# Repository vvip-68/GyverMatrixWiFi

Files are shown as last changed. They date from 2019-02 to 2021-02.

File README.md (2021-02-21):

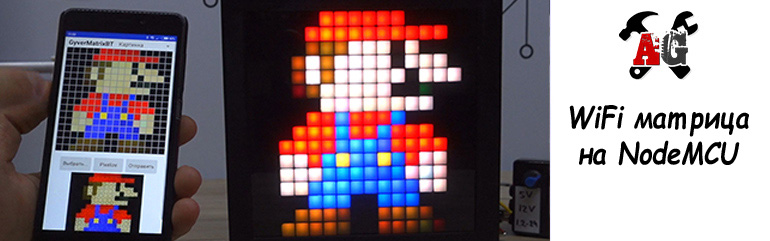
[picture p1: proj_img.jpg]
PROJECT_PHOTO


# Адресная матрица на NodeMCU с управлением по WiFi
* [Описание проекта](#chapter-0)
* [Папки проекта](#chapter-1)
* [Схемы подключения](#chapter-2)
* [Материалы и компоненты](#chapter-3)
* [Как скачать и прошить](#chapter-4)
* [FAQ](#chapter-5)
* [Полезная информация](#chapter-6)

> Этот проект устарел. Новый проект ["Широкоформатная матрица / гирлянда на балкон или стену с управлением по WiFi"](https://github.com/vvip-68/GyverPanelWiFi)
> полностью перекрывает функционал этого проекта, а также имеет множество доработок и улучшений.

## Описание проекта
Этот проект основан на проекте AlexGyver ["Матрица на адресных светодиодах с управлением по Bluetooth"](https://github.com/AlexGyver/GyverMatrixBT)
#### Изменения по справнению с исходным проектом:
 - Поддержка только контроллера с большим объемом памятии наличием WiFi на борту - NodeMCU, Wemos D1 
 - Другие типы контроллеров (типа Arduino Mega + WiFi) - не тестировались.
 - Удалена поддержка управления с кнопок
 - Оставлена одна кнопка управления для переключения режимов, отключения работающего будильника
 - Удалена поддержка управления по Bluetooth
 - Удалена поддержка платы часов реального времени
 - Управление матрицей - через WiFi (локальная сеть)
 - Синхронизация времени с NTP сервером через интернет
 - Адаптированная программа управления матрицей на Andrioid
 - Изменены настройки режимов воспроизведения эффектов
 - Настройки режимов можно изменять из программы со смартфона
   - Яркость матрицы - единая для всех режимов
   - Скорость эффектов - индивидуально для каждого режима
   - Наличие наложения часов на эффекты - индивидуально для каждого режима
   - Включение/исключение режима из списка любимых режимов
 - Настройки сохраняются в энергонезависимой памяти EEPROM
 - К режиму часов добавлен календарь - кратковременное отображение текущей даты поверх эффекта
 - Настройка сервера синхронизации времени
 - Будильник "рассвет", настройки через программу на смартфоне, 7 будильников на каждый день
 - Поддержка звука будильника  / звука рассвета звуковой платой MP3 DFPlayer
 - Настройки сетевого подключения (SSID и пароль, статический IP) задаются в программе и сохраняются в EEPROM
 - Если не удается подключиться к сети (неверный пароль или имя сети) - создается точка подключения
   с именем MatrixAP, пароль 12341234, IP 192.168.4.1. Подключившись к точке доступа из приложения
   можно настроить параметры сети. Если после задания параметиров сети WiFi соединение установлено - 
   в приложении на смартфоне виден IP адрес подключения к сети WiFi.  
 - Быстрое включение режимов лампы белого или заданного цвета из приложения (вся панель светится), 
   выключение панели, комбинация лампы с отображением часов, ночные часы (пониженная яркость).
 - Автоматическая установка яркости матрицы в зависимости от уровня внешней освещенности.
 - Два программируемых по времени режима, позволяющие, например, настроить автоматическое выключение экрана матрицы в ночное время и автоматическое же включение матрицы утром.

## От исходного проекта сохранены следующие возможности:
#### Режимы:
 - Рисование
 - Загрузка картинок
 - Бегущая строка  
#### Эффекты:
 - Снегопад
 - Блуждающий кубик
 - Радуга
 - Огонь
 - The Matrix
 - Летающие частицы
 - Звездопад
 - Пейнтбол
 - Водоворот
 - Шумовые эффекты с разными цветовыми палитрами
 - Анимация
 - Часы  
#### Игры:
 - Змейка
 - Tетриc
 - Лабиринт  
 - Арканоид
 - Runner
#### Возможности:
- Автоподключение к матрице при запуске
- Настройки яркости и скорости отображения
- Использование акселерометра в играх

### Кнопка управления режимами, последовательность переключения:
#### Будильник сработал, идет рассвет или мелодия пробуждения
- Любое нажатие кнопки отключает будильник
#### Долгое удержание кнопки (более 3 секунд)
- Если матрица включена, она будет выключена (черный экран)
- Если матрица выключена (черный экран) - включается режим часов
#### Однократное нажатие кнопки
- Если матрица включена в режиме часов, происходит переключение часов по циклу:
  - Часы на черном фоне
  - Часы на фоне огня (камин)
  - Ночные часы
- Если матрица включена в режим лампы (белый экран) - вкл / выкл отображения часов.
- Если работают демо-режимы -  переход к следующему режиму
#### Двухкратное нажатие кнопки
- Из любого режима включается режим часов на черном фоне
- Из режима часов переключается в режим лампы
#### Трехкратное нажатие кнопки
- Включается демо-режим
#### Четырехкратное нажатие кнопки
- На экране матрицы в режиме бегущей строки отображается IP адрес матрицы, если подключение к локальной WiFi сети установлено

## Папки
**ВНИМАНИЕ! Если это твой первый опыт работы с Arduino, читай [инструкцию](#chapter-4)**
- **libraries** - библиотеки проекта.
- **firmware** - прошивки для NodeMCU
- **schemes** - схемы подключения компонентов
- **sounds** - звуковые файлы будильника для размещения на SD-карте
- **Android** - файлы с приложениями, примерами для Android и Thunkable
- **image decoding** - папка с инструментами для загрузки картинок и гифок

## Схемы
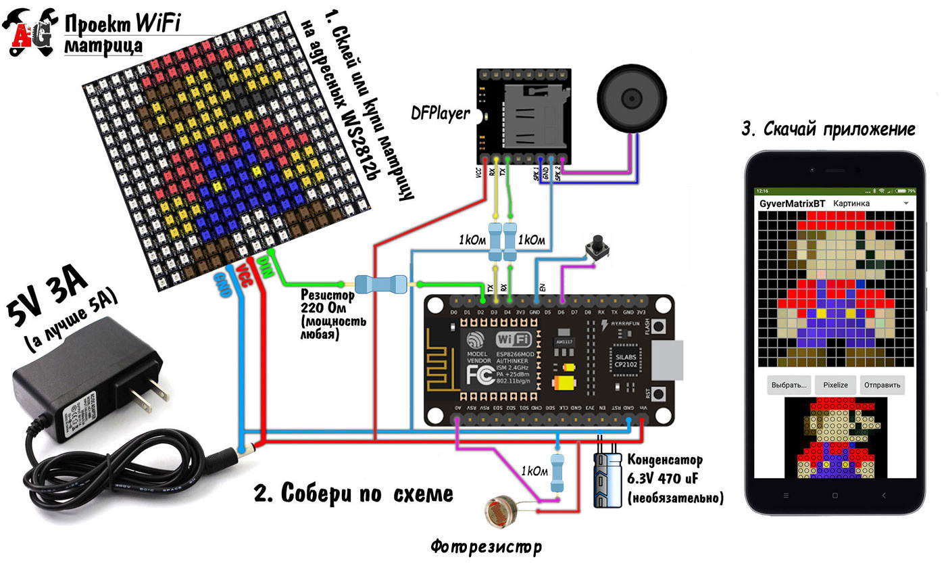
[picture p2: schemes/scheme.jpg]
SCHEME


## Материалы и компоненты
### Ссылки оставлены на магазины
Полный список компонентов есть в статье https://alexgyver.ru/matrix_guide/
- NodeMCU http://ali.onl/1dVU http://ali.onl/1dVV
- Матрицы разные http://ali.ski/pw2ic
- Лента http://ali.ski/YdfMN
- Модульная гирлянда http://ali.ski/0h35RR
- Резисторы http://ali.ski/UEez2
- БП 5 Вольт http://ali.ski/3cNyj  http://ali.ski/qSKFK
- MP3 DFPlayer http://ali.onl/1gY1 http://ali.onl/1gY3
- Динамики http://ali.onl/1h3u http://ali.onl/1h3v

## Вам скорее всего пригодится
* [Всё для пайки (паяльники и примочки)](http://alexgyver.ru/all-for-soldering/)
* [Недорогие инструменты](http://alexgyver.ru/my_instruments/)
* [Все существующие модули и сенсоры Arduino](http://alexgyver.ru/arduino_shop/)
* [Электронные компоненты](http://alexgyver.ru/electronics/)
* [Аккумуляторы и зарядные модули](http://alexgyver.ru/18650/)

## Как скачать и прошить
* [Первые шаги с Arduino](http://alexgyver.ru/arduino-first/) - ультра подробная статья по началу работы с Ардуино, ознакомиться первым делом!
* Скачать архив с проектом
> На главной странице проекта (где ты читаешь этот текст) вверху справа зелёная кнопка **Clone or download**, вот её жми, там будет **Download ZIP**
* Установить библиотеки в  
`C:\Program Files (x86)\Arduino\libraries\` (Windows x64)  
`C:\Program Files\Arduino\libraries\` (Windows x86)
* **Подключить внешнее питание 5 Вольт**
* Подключить Ардуино к компьютеру
* Запустить файл прошивки (который имеет расширение .ino)
* Настроить IDE (COM порт, модель Arduino, как в статье выше)
* Настроить что нужно по проекту
* Нажать загрузить
* Скачать и установить на смартфон GyverMatrix
* Пользоваться  

**Подробная инструкция [тут](https://github.com/vvip-68/GyverMatrixWiFi/wiki/%D0%9F%D0%BE%D0%B4%D0%B3%D0%BE%D1%82%D0%BE%D0%B2%D0%BA%D0%B0-%D1%81%D1%80%D0%B5%D0%B4%D1%8B-%D0%B4%D0%BB%D1%8F-%D1%81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)**

## Важно
Если проект не собирается (ошибки компиляции) или собирается, но работает неправильно (например вся матрица светится белым и ничего не происходит) - проверьте версии библиотек. Данный проект рассчитан на работу с версииями библиотек поддержки плат ESP версии 2.5.2 и библиотеки FastLED версии 3.2.9 или более новую;

Если в качестве микроконтроллера вы используете Wemos D1 - в менеджере плат для компиляции все равно выбирайте **"NodeMCU v1.0 (ESP-12E)"**, в противном случае, если выберете плату Wemos D1 (xxxx), - будет работать нестабильно, настройки не будут сохраняться в EEPROM, параметры подключения к локальной сети будут сбрасываться каждый раз при перезагрузке, плата вместо подключения к локальной сети будет каждый раз создавать точку доступа.

## FAQ
### Основные вопросы
В: Как скачать с этого грёбаного сайта?  
О: На главной странице проекта (где ты читаешь этот текст) вверху справа зелёная кнопка **Clone or download**, вот её жми, там будет **Download ZIP**

В: Скачался какой то файл .zip, куда его теперь?  
О: Это архив. Можно открыть стандартными средствами Windows, но думаю у всех на компьютере установлен WinRAR, архив нужно правой кнопкой и извлечь.

В: Я совсем новичок! Что мне делать с Ардуиной, где взять все программы?  
О: Читай и смотри видос http://alexgyver.ru/arduino-first/

В: Вылетает ошибка загрузки / компиляции!   
О: Читай тут: https://alexgyver.ru/arduino-first/#step-5

### Вопросы по этому проекту

В: Эй чувак! У тебя проект не компилится. Ты файл DFRobotDFPlayerMini.h в проект забыл включить. Выложи!   
О: Это стандартная библиотека для MP3 DFPlayer. Идите в менеджер библиотек и установите ее. Или скачайте с [сайта производителя](https://github.com/DFRobot/DFRobotDFPlayerMini)

В: Эй чувак! У тебя проект не компилится. Ты файл FastLed.h в проект забыл включить. Выложи!   
О: Это стандартная библиотека для FastLed для управления адресными светодиодами. Идите в менеджер библиотек и установите ее. Или скачайте с [сайта производителя](https://github.com/FastLED/FastLED)

В: Собрал, использую NodeMCU/Wemos. Ничего не работает! Мигает один или несколько светодиодов в начале матрицы. И всё.   
О: Производители разных плат (NodeMCU, Wemos) могут использовать различные схемы соединения контактов микроконтроллера ESP8266 к выводам макетной платы. Обычно используемый в проекте пин вывода на ленту приходится или на пин D2 или на пин D4. Для проверки не подключайте сигнальный провод матрицы к микроконтроллеру, вместо этого через резистор коснитесь вывода D2 или D4 пина микроконтроллера. Большая вероятность что матрица заработает с тем или иным вариантом подключения.

В: Собрал, использую NodeMCU. Эффекты работают, но нестабильно. Случайные вспышки на матрице. Буквы бегущей строки прыгают.   
О: NodeMCU v3 чрезвычайно требователен к источнику питания. Ему на вход VIN нужно подавать напряжение в диапазоне 4.7-5 вольт. И не более. Описанные эффекты возникают даже при питании в 5.25 (а тем более - 5.45) вольт. Для проверки - не подключайте +5 вольт от блока питания к NodeMCU совсем, питание подавайте на матрицу непосредственно. Землю NodeMCU и ленты соедините. Подключите сигнальный пин NodeMCU ко входу DIN ленты. Подключите NodeMCU к компьютеру через USB (питание будет поступать отсюда). Должно заработать. Далее регулируйте выходное напряжение своего блока питания.  
В особо тяжелых случаях, когда понижение напряжения питания системы не приводит к желаемым результатам и артефакты, вспышки, дрожание текста бегущей строки продолжается, можно использовать дополнительно схему преобразования уровня от 3.3 вольта с выхода NodeMCU к 5 вольтам входа адресной ленты:  
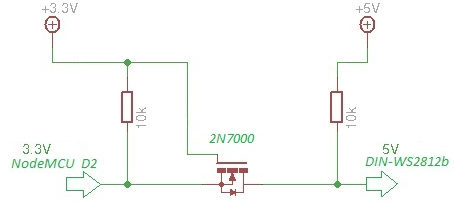
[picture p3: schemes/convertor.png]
SCHEME


В: Не компилируется. Выбрана плата "голая ESP8266-12E". Сообщение об ошибке: "D4 was not declared in this scope."   
О: Очевидно производители библиотеки для "голой ESP8266-12E" не определили данную константу. Используйте всесто константы D4 числовое определение пина для вашей платы или выполните компиляцию проекта для плат NodeMCU или WeMos D1 R2.

В: Не компилируется. В сообщении об ошибке содержатся сведения о дублирующихся библиотеках.    
О: В вашей среде установлено две версии одной и той же библиотеки. Обычно это библиотека FastLED - одна версия находится в папке установки среды Ардуино (например в "C:\Program Files (x86)\Arduino\libraries\"), другая - в папке документов пользователя (например "C:\Users\vvip-68\Documents\Arduino\libraries\"). Удалите одну из версий библиотек и попробуйте скомпилировать снова.

В: Не компилируется. В сообщении об ошибке что-то про несоответствие типов.   
О: Обычно такая ситуация возникает в двух случаях:
- выбрана неверная плата. Используйте NodeMCU 1.0 (ESP-12E Module) или Wemos D1 R1. Под эти платы проект собирается, под другие, возможно, нужна модификация кода.
- установлена устаревшая версия библиотек поддержки плат - например для ESP8266 версия библиотеки 2.4.2. Данный проект использует библиотеки для плат ESP8266 версии 2.5. Обновите библиотеки поддержки плат.

В: Подскажите, что не так... C подключением через точку доступа всё исправно работает, а при попытке подключиться к локальной сети не могу законнектиться через приложение. В чем может быть проблема?  
О: Проблема может быть в неправильно указанном статическом адресе / параметрах сети в прошивке. В сектче по умолчанию используется адрес в сети 192.168.**0**.xxx. Ваш WiFi роутер в зависимости от настроек может создавать сеть в другом диапазоне. Чаще всего это 192.168.**1**.xxx или 192.168.**100**.xxx; Проверьте какую сеть создает ваш роутер и укажите в скетче и при подключении приложения к сети именно эту сеть.

В: Автор неверно указал IP адрес матрицы 192.168.4.1 в режиме точки доступа. На самом деле он 192.168.4.2 - указываю его, приложение на смартфоне подключается. Правда управлять матрицей не получается все равно - она не реагирует на изменения.     
О: Нет, все правильно. IP матрицы - 192.168.4.1; Адрес 192.168.4.2 получает ваш смартфон при подключении к точке доступа. Когда в приложении для подключения вы указываете адрес 192.168.4.2 - вы подключаете ваш смартфон с самому себе, а не к матрице. Естественно никакое управление матрицей работать не будет.   

В: Матрица создает точку доступа, телефон к ней подключается. В приложении ввожу IP адрес матрицы 192.168.4.1, но соединение не происходит. Что я делаю не так?     
О: Некоторые телефоны не могут передавать данные через точку доступа, пока в них активен мобильный интернет. Все передаваемые данные отправляются в интернет, вместо передачи их в точку доступа. В настройках телефона выключите мобильный интернет ("Мобильные данные"). После этого телефон из приложения должен подключиться к матрице.  

В: В скетче есть настройки который задают имя и пароль к локальной сети. Указываю, но к сети даже не пытается подключиться В чем дело?     
#define NETWORK_SSID ""                      // Имя WiFi сети - пропишите здесь или задайте из программы на смартфоне    
#define NETWORK_PASS ""                      // Пароль для подключения к WiFi сети - пропишите здесь или задайте из программы на смартфоне      
О: Эти настройки определяют параметры доступа к сети по умолчанию, которые используются при ПЕРВОЙ загрузке прошивки в матрицу. В этот момент они сохраняются в EEPROM и при последующих запусках имя сети и пароль извлекаются из энергонезависимой памяти и используются уже извлеченные значения, а не те, что прописаны в #define. Если вы уже запускали матрицу и ПОСЛЕ этого изменили в скетче имя и пароль сети, вам нужно также изменить значение флага, указывающее было ли уже сохранение параметров в EEPROM или еще нет. Этот флаг находится в файле eeprom.ino в первой строке  
#define EEPROM_OK 0x5A                     // Флаг, показывающий, что EEPROM инициализирована корректными данными 
Измените его на любое другое значение, например 0xA5

### Всё собрал строго по инструкции, ничего не работает.

1. Разбираем всё обратно.
2. Берем платку, смотрим чтобы к ней НИЧЕГО не было подключено.
3. Плату в таком состоянии подключаем кабелем USB к компьютеру.
4. Берем последнюю версию [прошивки](https://github.com/vvip-68/GyverMatrixWiFi/) и загружаем ее в микроконтроллер.
5. Смотрим в сообщениях, что загрузка успешно выполнена и осуществлен перезапуск микроконтроллера, а в мониторе порта, что скетч стартовал, вывел версию прошивки, создал точку доступа MatrixAP
6. Устанавливаем на смартфон приложение из этого проекта
7. Подключаемся телефоном к точке доступа, приложение подключаем к матрице, пробуем тыкать на кнопки.
8. Отключаем микроконтроллер от компьютера
9. Подключаем блок питания +5 вольт и минусовой провод к матрице. Минусовой провод подключаем также к пину GND микроконтроллера.
Контроллер подключаем USB кабелем к компьютеру, блок питания включаем в сеть.
10. Проверяем, что напряжение питания с блока не превышает +5.25 вольт. Если больше - регулируем его до уровня 4.8 вольта.
11. Сигнальным проводом с матрицы с подключенным резистором 200 Ом тыкаемся поочередно в пины D4 и D2 микроконтроллера. В каком-то из этих двух вариантов на иматрице должно сформироваться осмысленное отображение эффекта, игры или бегущего текста. Что из этого конкретно должно в данный момент отображаться - написано в мониторе порта. Запоминаем подключение к какому пину дало результат.
12. Отключаем микроконтроллер и блок питания. Провод +5V с блока питания подключаем к микроконтроллеру на пин его входного напряжения питания (у разных плат обозначен по разному - Vin, Vcc или +5). Сигнальный провод матрицы припаиваем к пину, который определили шагом выше. Очень желательно между пинами Vin и GND микроконтроллера припаять электролитический конденсатор номиналом 1000-4700 мкф, и параллельно ему керамический конденсатор на 33-100 нф.
13. Включаем блок питания в розетку. Матрица должна заработать.
14. Собираем всю конструкцию в корпус. Если матрица это гирлянда - развешиваем ее.

## Полезная информация
* [Cайт Alex Gyver](http://alexgyver.ru/)
* [Канал Alex Gyver на YouTube](https://www.youtube.com/channel/UCgtAOyEQdAyjvm9ATCi_Aig?sub_confirmation=1)
* [YouTube канал про Arduino](https://www.youtube.com/channel/UC4axiS76D784-ofoTdo5zOA?sub_confirmation=1)
* [Видеоуроки по пайке](https://www.youtube.com/playlist?list=PLOT_HeyBraBuMIwfSYu7kCKXxQGsUKcqR)
* [Видеоуроки по Arduino](http://alexgyver.ru/arduino_lessons/)

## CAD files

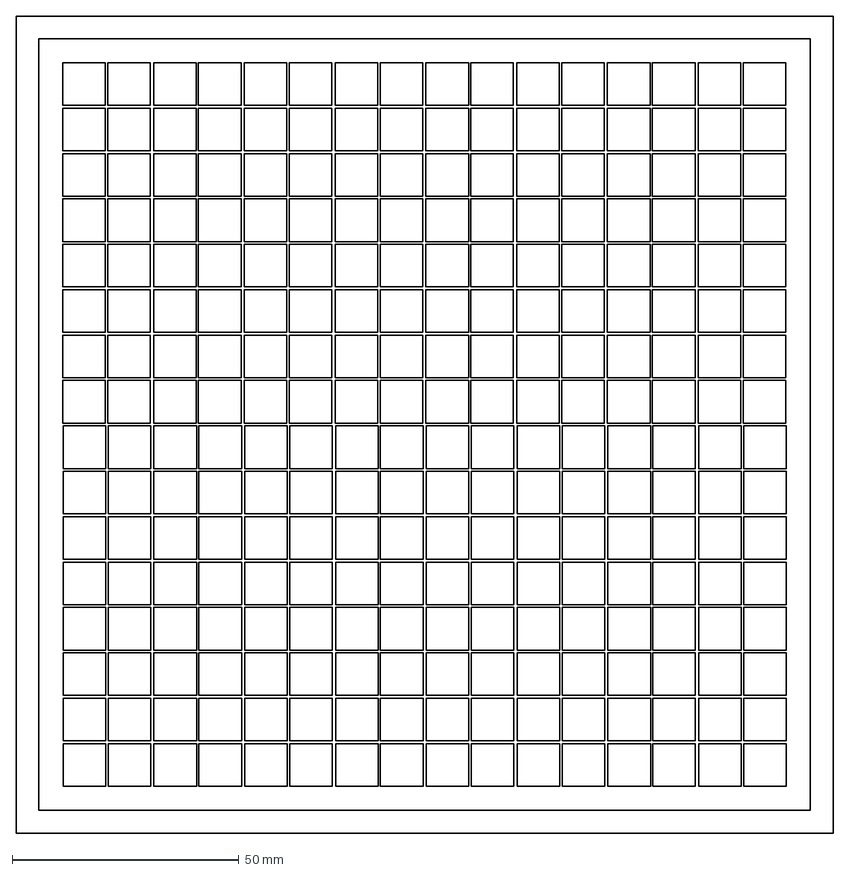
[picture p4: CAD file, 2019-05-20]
cnc/решетка.dxf
180.0 x 180.0 mm

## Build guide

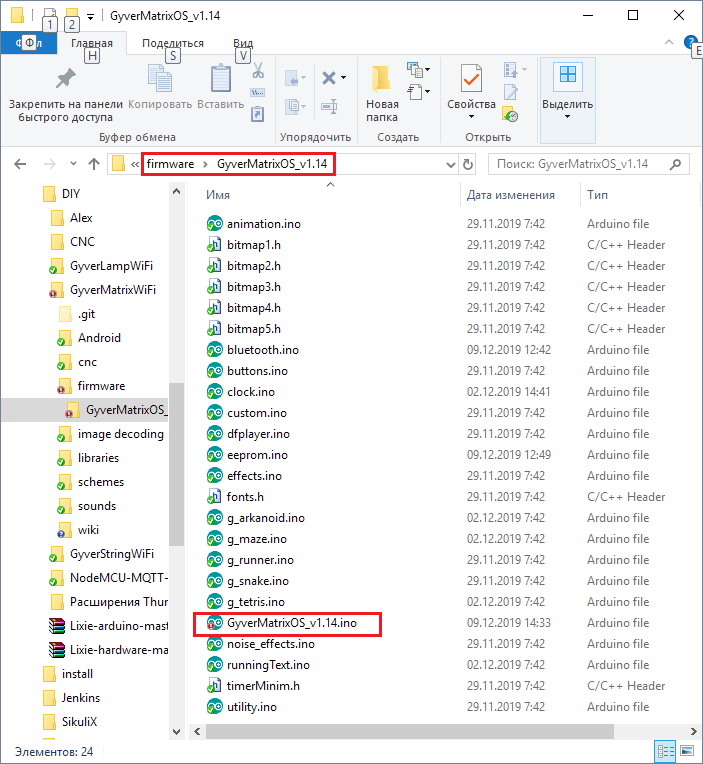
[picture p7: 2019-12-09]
wiki/Step_07_1.png

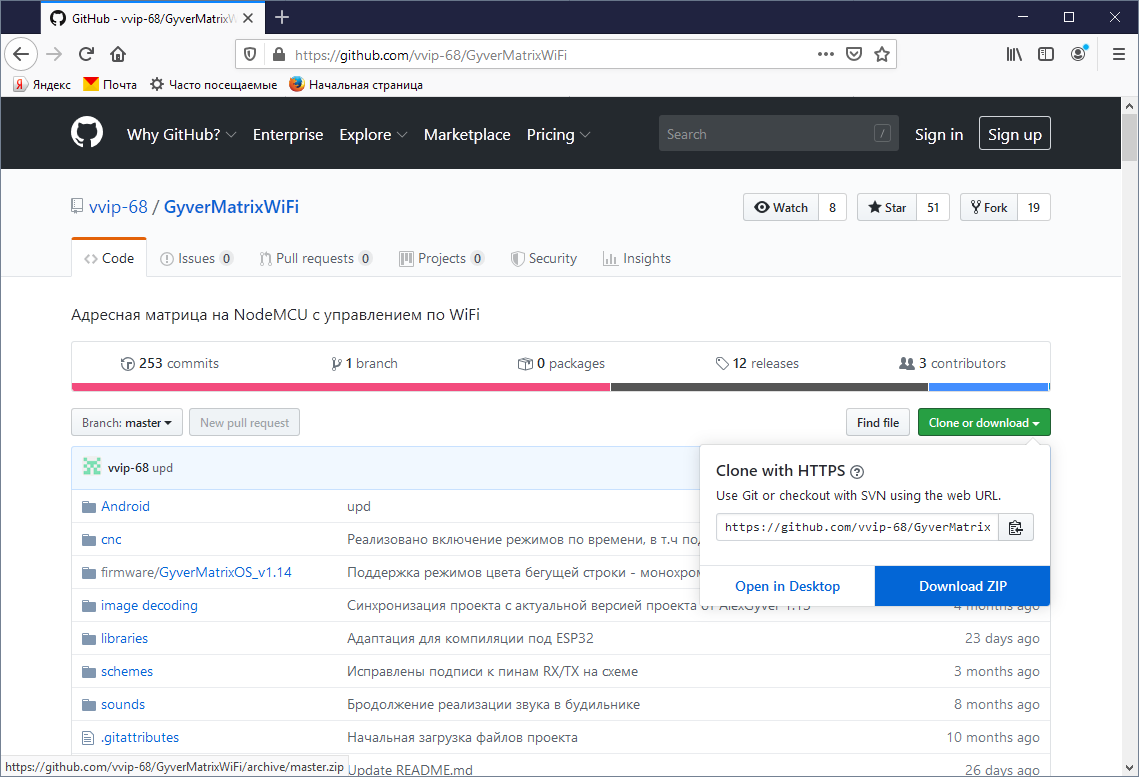
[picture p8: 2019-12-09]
wiki/Step_04_1.png

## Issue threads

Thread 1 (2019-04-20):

Не компилируется

Cherkes001, 2019-04-20:
[Скрин](https://imgur.com/qhs41Js)

aka-inc, 2019-04-22:
Нужно выбрать в менеджере плат WeMos D1 R2. Под неё у меня компилируется.

Cherkes001, 2019-04-22:
> Нужно выбрать в менеджере плат WeMos D1 R2. Под неё у меня компилируется.
А на что заливаешь? NodeMCU или WeMos?

aka-inc, 2019-04-23:
на голую ESP8266-12E с 1Мб памяти. Микроконтроллер на этих платах один и тот же, отличается наличием дополнительных резисторов, USB-TTL и прочим обвесом. Если компилирую под Generic ESP8266 или NodeMCU, то тоже не компилируется. На более ранних версиях были ошибки в функциях работы с кнопками и блютуз, я ошибки исправлял, и всё компилировалось под любые платы ESP8266.

Cherkes001, 2019-04-24:
> на голую ESP8266-12E с 1Мб памяти. Микроконтроллер на этих платах один и тот же, отличается наличием дополнительных резисторов, USB-TTL и прочим обвесом. Если компилирую под Generic ESP8266 или NodeMCU, то тоже не компилируется. На более ранних версиях были ошибки в функциях работы с кнопками и блютуз, я ошибки исправлял, и всё компилировалось под любые платы ESP8266.

Скомпилировал под WeMos, все работает отлично, спасибо за совет

vvip-68, 2019-04-24:
В копилку опыта...

Closed 2019-04-24.

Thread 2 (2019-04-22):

Добавление цветомузыки и управления от микрофона

aka-inc, 2019-04-22:
Есть ли возможность прикрутить эффект цветомузыки? Через микрофон (LineOut) на единственный аналоговый вход ESP8266. Также можно выключать будильник хлопком в ладоши.. или включать следующий режим эффектов двойным хлопком.

Спаял матрицу 15х20 размером 3,8х3,5 метра на весь потолок на микроконтроллере ESP8266-12E, который разместил внутри блока питания 5В 20А. Чтобы избавиться от наводок и глюков, использовал коаксиальный кабель на DIN светодиодной ленты, ферритовое кольцо на линии питания контроллера, обвязку из конденсаторов, а также пришлось понизить напряжение на светодиодах до 4.4В. Причём на ардуине с её питанием 5В глюки на матрице большого размера тоже налюдаются, если не понизить напряжение до 4.4В. Глюки проявляются на контрастных режимах с резким переключением яркости диодов, и добавление конденсатора в линию питания контроллера и ленты ничего не даёт. А при пониженном напряжении ничего не глючит, нет спонтанных вспышек и артефактов, но яркость сильно ниже, и цветовой спектр диодов становится очень узкий. Увличение расстояния контроллера от блока питания и его экранирование фольгой не влияют на глюки. Они явно связаны с рассогласованием уровней сигнала контроллера и питания.

vvip-68, 2019-04-24:
Ну, я этим заниматься не буду. Мне это направление не интересно. Если сделаете и это будет работать - включим код в проект...
Для маленьких матриц (типа 16x16) больше, видимо, дописывать ничего не предвидится.
Когда соберу большую настенную размерами примерно 30х40 - посмотрю как будет работать и, видимо немного допишу чего-нибудь в плене отображения. Например часы бОльшим шрифтом, расстояние между цифрами большее, чтоб точки не сливались, может быть "гуляние" часов по экрану, отображение вместе с датой...

Closed 2019-05-05.

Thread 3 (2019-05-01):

Включение/выключение по расписанию

serg-74, 2019-05-01:
Здравствуйте.
Есть ли возможность возможность сделать включение/выключение (опционально) матрицы по расписанию (например, включение в 17.30, выключение в 23.00). Т.е. ESP8266 включена постоянно, а на матрицу сигнал подается согласно расписания. Как вариант, возможно использовать компьютерный блок питания ATX - ESP8266 питать от 5В дежурного режима блока питания, а для питания ленты использовать линию 5В, управлять блоком питания можно сигналом с ESP8266.

vvip-68, 2019-05-06:
Теоретически это сделать не сложно. А практически - ну, может, руки и дойдут когда-нибудь... Это рутинная не интересная доработка программы. К тому же нужно менять управление в Android-программе (время, когда выключить, когда включить, чекбоксы использовать / нет) - это всё в Thunkable, а он и с текущим функционалом уже еле шевелится. Что-то менять там - одно мучение...

vvip-68, 2019-05-20:
Сделал такие режимы. В приложении на смартфоне добавлен пункт в списке выбора / страничка настроек "Режимы по времени". Два режима для которых можно задать время срабатывания и действие, которое нужно выполнить. Если выбрано "Нет действия" - при наступлении указанного времени ничего не происходит, иначе выполняется одно из действий, указанных в списке.
Список действий:
  - Выключить матрицу
  - Включить ночные часы
  - Включить камин с часами
  - Включить бегущую строку (текст нужно задать в настройках текста бегущей строки)
  - Включить случайный эффект и далее смена эффектов - режим демонстрации
  - Включить выбранный из списка эффект . Автосмена на другой эффект отключена.
То есть, для 23:00 вы можете выбрать действие "Выключить матрицу", а для 17:30 - "Случайный эффект". ESP8266 при этом остается активной - матрицей можно управлять со смартфона или кнопкой, если включен будильник - он сработает. По завершении работы будильника матрица останется включенной в режиме отображения часов.

vvip-68, 2019-06-20:
Исправление к выше (в связи с выходом новой версии):
"... По завершении работы будильника матрица вернется в режим, который был до срабатывания будильника. То есть, если матрица была "выключена" - после завершения работы будильника она вернется в состояние "выключено". "

Closed 2019-05-06.

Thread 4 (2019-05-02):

Как победить глюки?

Cherkes001, 2019-05-02:
Под глюками подразумевается включение группы случайных светодиодов.
Пробовал понижать напряжение на ноде до 4.5 и ниже на NodeMCU через Buck преобразователь, но это ничего не дало, так же кинул на выход преобразователя параллельно конденсатор 6.3v  1000uF для сглаживания на случай помех от пульсаций, что так же не дало результата.
(Тестирую на маленькой самосборной матрице 6х6 из ленты, в дальнейшем контроллер будет подключен на большом окне 2.4×1.4м)

serg-74, 2019-05-02:
Напряжение надо понижать не на контроллере, а на ленте (матрице).

Cherkes001, 2019-05-03:
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

Хорошо, попробую

Cherkes001, 2019-05-03:
Чекнул, все то же самое

vvip-68, 2019-05-05:
Напряжение нужно понижать на всем сразу - и на контроллере и на матрице. Уровни должны быть согласованы. Про то, почему могут быть такие глюки - у Гувера расписано https://alexgyver.ru/gyvermatrixbt/. Других вариантов нет.
Могу предложить для теста питание с БП подавать только на ленту, землю МК и ленты - связать, сам МК питать от USB подключенному к компу.

Closed 2019-05-05.

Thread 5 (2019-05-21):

dawnColorSat2 causes a section type conflict with __c

yusufsulaiman, 2019-05-21:
hi. i have error dawnColorSat2 causes a section type conflict with __c

vvip-68, 2019-05-21:
Hi,
I have no such error. Possible you are doing something wrong.

vvip-68, 2019-05-22:
Couldn`t reproduce issue.

AndrewVlz, 2019-09-23:
Добрый день!

Получил такую же ошибку при компиляции Вашей программы.

"dawnColorSat2 causes a section type conflict with __c"

скетч effects.ino.

При этом dawnColorSat с таким же содержимым ошибок не вызывает.

Настройки компиляции, версия Arduino IDE прилагаются.

В чем может быть проблема?

Спасибо!
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

vvip-68, 2019-10-01:
Снова скажу - ни разу не видел такой ошибки. Возможно это проблемы компилятора. У вас довольно старая версия IDE 1.8.2, gjghj,eqnt обновиться до последней - 1.8.10. На версиях IDE 1.8.9 и 1.8.10 такой ошибки при компиляции у меня не возникает.

vvip-68, 2019-10-02:
Проблема в том, что у вас старая версия библиотеки ядра ESP8266 (скорее всего 2.4.x вместо рекомендованной 2.5.2) и вы совсем не читаете инструкции к проекту

yusufsulaiman, 2019-10-11:
thanks for advice. i have made it
https://www.youtube.com/watch?v=ZucOUIFpxck

Closed 2019-05-22.

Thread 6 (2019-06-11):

Версии библиотек

serg-74, 2019-06-11:
Здравствуйте.
При попытке повторить устройство столкнулся с проблемой: работает только первый светодиод (выбрана плата LOLIN(WEMOS) D1 R2 & mini, если выбираю плату WeMos D1 R1 - то работает только первых 63 светодиода.
Менеджер плат ESP8266 версии 2.5.0
Версия платформы Arduino 1.6.10 и 1.8.9
Версия библиотеки FastLEd 3.2.9
Проверено на 2-х разных платах. Плеер, кнопку и датчик освещенности не использую.
Подскажите Ваши версии: платформы, менеджера плат, выбранный тип платы, версии используемых библиотек.
Спасибо.

vvip-68, 2019-06-20:
Для тех, кто сам не разобрался: версия библиотеки поддержки плат ESP8266 должна быть 2.5.2 - только с этой версией работает обновленная FastLED 3.2.9

Closed 2019-06-11.

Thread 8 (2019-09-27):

Выложить исходники Android/iOs приложений

khvalov, 2019-09-27:
День добрый.
Есть ли возможность выложить исходники Android/iOs приложений для улучшения их функционала ?

vvip-68, 2019-09-28:
Для андроида исходник есть в проектe - папка Android, файл GyverMatrixWiFi.aia - открывайте его в Thunkable и правьте как нужно. Для iOS, насколько я понимаю программы в природе не существует. Но вы можете сами написать ее под себя.

Closed 2019-09-28.

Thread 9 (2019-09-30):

dawnColorSat2 causes a section type conflict with __c

AndrewVlz, 2019-09-30:
Добрый день!

Вынужден переоткрыть ранее закрытый issue.

Получил такую же ошибку при компиляции Вашей программы.

"dawnColorSat2 causes a section type conflict with __c"

скетч effects.ino.

При этом dawnColorSat с таким же содержимым ошибок не вызывает.

Настройки компиляции, версия Arduino IDE прилагаются.

В чем может быть проблема?
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

Спасибо!

vvip-68, 2019-10-01:
Попробуйте для начала поставить последнюю версию ArduinoIDE - 1.8.10 и попробовать скомпилить скетч в ней.

AndrewVlz, 2019-10-01:
Спасибо за совет!

Установил Arduino IDE 1.8.10.

1. clock.ino - для строки " if (!timeServerIP.isSet()) timeServerIP.fromString(F("192.36.143.130"));  // Один из ru.pool.ntp.org // 195.3.254.2" выдается ошибка:

clock:82:21: error: 'class IPAddress' has no member named 'isSet'.

Закомментировал данную строку (кстати, компилятор "ругался" на неё и в предыдущей версии).

2. effects.ino - вновь та же ошибка:

dawnColorSat2 causes a section type conflict with __c.

В настройках компиляции перебрал оба NodeMCU и все четыре WeMos - ошибка та же.

В чем же проблема?

Я приложил сообщения об ошибках в текстовом файле - возможно, это поможет найти решение.
[Errors.txt](https://github.com/vvip-68/GyverMatrixWiFi/files/3677666/Errors.txt)

vvip-68, 2019-10-02:
Проблема в том, что у вас старая версия ядра ESP8266 и вы совсем не читаете инструкции к проекту...

Closed 2019-10-02.

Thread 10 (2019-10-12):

Картинка сбрасывается после таймаута

khvalov, 2019-10-12:
В режиме загрузки картинки - по истечении таймаута программа переходиит обратно в демо режим. ИМХО было бы логично сохранять картинку или до сброса или до принудительного перевода экрана в режим отличный от картинки (например если хочешь отображать логотип до тех пор пока не сбросишь его)

vvip-68, 2019-10-13:
Отключение автоперехода в демо режим не решает ситуацию?

khvalov, 2019-10-14:
С автопереходом я попробую поиграться, но полное отключение демо режима не решает проблему. В НЕ-Демо режиме черех (примерно) 5 минут программа переходит в режим отображения времени

khvalov, 2019-10-14:
Попробуйю сегодня и отпишусь

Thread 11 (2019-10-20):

Вынести модуль переводов на разные языки

khvalov, 2019-10-20:
Сделать возможность перевести интерфейс приложения (Андроид) на разные языки

vvip-68, 2019-10-21:
А это в принципе в Thunkable возможно? Не думаю, что это так.
В любом случае - исходник есть - дерзайте! DIY.

Closed 2019-10-21.

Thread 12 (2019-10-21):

Не могу разобраться, не работают 3 эффекта

Evgeny161rus, 2019-10-21:
При выборе в приложении эффектов "Дыхание", "Цвета" и "Радуга Пикс" Картинка на матрице виснет, так же, чекбоксы "Часы поверх эффекта" и "Использовать в Демо-режиме" становятся неактивными. При выборе любого другого эффекта всё работает. Node Mcu менял, прошивал разными прошивками, и от Gyvera, и этой, эффекта ноль, приложение переустанавливал. Что я делаю не так?

vvip-68, 2019-10-22:
Всё так. Эти "эффекты" - на самом деле не эффекты, а нечто специфическое, что работает практически только для бегущей строки (и, возможно, в режиме рисования). При их включении в бегущей строке (в нарисованной картинке) она плавно пульсирует яркостью или меняет свой цвет по радуге. Из за их специфичности недоступна галочки "Использовать" и "Часы". Остались рудиментом от самой первой версии матрицы от Гайвера. По хорошему их (эти три эффекта) вообще надо либо выкинуть либо перенести на страничку Текста. Но переделывать уже как-то лень. Времени потратить нужно много, а "выхлопа" с этого - чуть.

Evgeny161rus, 2019-10-22:
Вот да, если бы их перенести на страничку текста, было бы идеально. Я не гуру в программировании, поэтому не осилю

Closed 2019-10-22.

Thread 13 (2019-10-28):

Can you translate these fields of aia file into english for us?

tihoangyeudau, 2019-10-28:
I cant change these fields of aia file into english https://i.imgur.com/6jrF2kT.jpg https://i.imgur.com/sT5VTZD.jpg

Can u help me? Using it by russian make me difficult to use.

vvip-68, 2019-10-28:
Настройки - Settings
Подключить - Connect

tihoangyeudau, 2019-10-31:
Thank you i can do it.

Closed 2019-10-28.

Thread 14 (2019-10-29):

Проблема с приложением android

Kenaed, 2019-10-29:
1. В приложении если при работе с рисовалкой из неё выйти и снова войти все ячейки пустые, но продолжается рисование как будто они заполнены

2. Идея модернизации: сделать в рисовалке кнопку получить код, чтоб то что нарисовано получить в виде кода, и желательно в том же виде, который вставляется во вкладке анимация, и кнопку вставить код. Это позволит хранить и не перерисовывать одни и те же рисунки.

vvip-68, 2019-10-30:
А если ты вышел из рисовалки, включил какой-то эффект, все нарисованное на матрице стерлось/поменялось, а потом ты вернулся обратно в рисовалку. Что по твоему должно быть в приложении в поле рисования? ИМХО этот сценарий гораздо более частый, поэтому при включении в программе страницы "Рисование" имеем черный экран.

Впрочем - исходники открытые. Ты можешь написать спец-протокол, по которому программа будет запрашивать матрицу что она светит и в программе это же отображать. Хотя, если изображение все время меняется - в программе ты все равно получишь неактуальное.

По модернизации - код открытый. В т.ч. и приложения. Пиши хотелки под себя. Как напишешь рабочую версию - делай Pull request. Если все работать будет - включу в проект.

Kenaed, 2019-10-30:
захожу во вкладку рисование, рисую, перехожу в настройки (не меняя режима) возвращаюсь в рисование и происходит то что я написал, добавь хоть чтоб поле если чистое при заходе и матрица чистилась

vvip-68, 2019-10-30:
Это не предусмотрено специально еще с версии, написанной Гайвером. И я в этом плане ничего переделывать не стал. Не чистится, потому что играя, например в змейку или во что там еще - можно поставить паузу, переключиться в режим рисования и нарисовать дополнительные препятствия. Или Нарисовав рисунок переключиться в эффекты и включить цветовые эффекты типа "Дыхание" или Радуга пикс.
В общем всё работает именно так как задумывалось изначальным автором и это не баг, это фича. Лично мне это не мешает и тратить время на такого типа хотелки я не стану.
Код открытый. Возьми и сделай как тебе нужно всё под себя.

Kenaed, 2019-10-30:
можешь тогда подсказать в каком месте ведется передача данных в контроллер?

vvip-68, 2019-10-30:
блок-процедура sendText

Closed 2019-10-30.

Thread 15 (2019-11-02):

Скорость игр в демо-режиме

Dante6214, 2019-11-02:
Уважаемый **vvip-68**, не могли бы проверить такой момент: выбираю каждую из игр, настраиваю скорость - минимальную. Но когда выбираю режим "демо", то скорость возрастает на максимум или почти на максимум. Только в играх. Если снова захожу в игры - скорость стоит в минимуме. В остальных эффектах скорость сохраняется такой, какую выбрал (опять же минимум, например) и самопроизвольно не меняется.

vvip-68, 2019-11-03:
Ну так то скорость игр в демо режиме постоянна и задается константой в скетче, а скорость игры настраиваемая - действует только в ручном режиме. То есть - они не связаны.
Ну хорошо, изменил скетч так, чтобы в демо-режиме игры отображались с той же скоростью, что была задана в настройках. Обновил скетч в репозитории. Попробуйте, отпишитесь что получилось.

Dante6214, 2019-11-03:
Спасибо большое, все работает. Скорость игр в демо остаётся как выбрал в настройках

Closed 2019-11-03.

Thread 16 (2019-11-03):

Can you help me to write character code interpreter in font HEX array?

tihoangyeudau, 2019-11-03:
i took a long time to make all characters code (ASCII) but i cant write them interpreter in font HEX array. can you help me to do it?
My code in runningtext.h with label (but not working correctly):
// интерпретатор кода символа в массиве fontHEX (для Arduino IDE 1.8.* и выше)
uint8_t getFont(uint8_t font, uint8_t row) {
  font = font - '0' + 16;   // translate code from ASCII-code into character images array index
  if (font <= 90) return pgm_read_byte(&(fontHEX[font][row]));     // for english chars
  else if (font >= 96 && font <= 224) {
    return pgm_read_byte(&(fontHEX[font - 17][row]));
  }
}

And my all characters code (ASCII) that i made:

const uint8_t fontHEX[][5] PROGMEM = {
   { 0x00, 0x00, 0x00, 0x00, 0x00 },   //   0x20  32
   { 0x00, 0x00, 0x5F, 0x00, 0x00 },   // ! 0x21  33
   { 0x00, 0x07, 0x00, 0x07, 0x00 },   // " 0x22  34
   { 0x14, 0x7F, 0x14, 0x7F, 0x14 },   // # 0x23  35
   { 0x24, 0x2A, 0x7F, 0x2A, 0x12 },   // $ 0x24  36
   { 0x4C, 0x2C, 0x10, 0x68, 0x64 },   // % 0x25  37
   { 0x36, 0x49, 0x55, 0x22, 0x50 },   // & 0x26  38
   { 0x00, 0x05, 0x03, 0x00, 0x00 },   // ' 0x27  39
   { 0x00, 0x1C, 0x22, 0x41, 0x00 },   // ( 0x28  40
   { 0x00, 0x41, 0x22, 0x1C, 0x00 },   // ) 0x29  41
   { 0x14, 0x08, 0x3E, 0x08, 0x14 },   // * 0x2A  42
   { 0x08, 0x08, 0x3E, 0x08, 0x08 },   // + 0x2B  43
   { 0x00, 0x00, 0x50, 0x30, 0x00 },   // , 0x2C  44
   { 0x10, 0x10, 0x10, 0x10, 0x10 },   // - 0x2D  45
   { 0x00, 0x60, 0x60, 0x00, 0x00 },   // . 0x2E  46
   { 0x20, 0x10, 0x08, 0x04, 0x02 },   // / 0x2F  47
   { 0x3E, 0x51, 0x49, 0x45, 0x3E },   // 0 0x30  48
   { 0x00, 0x42, 0x7F, 0x40, 0x00 },   // 1 0x31  49
   { 0x42, 0x61, 0x51, 0x49, 0x46 },   // 2 0x32  50
   { 0x21, 0x41, 0x45, 0x4B, 0x31 },   // 3 0x33  51
   { 0x18, 0x14, 0x12, 0x7F, 0x10 },   // 4 0x34  52
   { 0x27, 0x45, 0x45, 0x45, 0x39 },   // 5 0x35  53
   { 0x3C, 0x4A, 0x49, 0x49, 0x30 },   // 6 0x36  54
   { 0x01, 0x71, 0x09, 0x05, 0x03 },   // 7 0x37  55
   { 0x36, 0x49, 0x49, 0x49, 0x36 },   // 8 0x38  56
   { 0x06, 0x49, 0x49, 0x29, 0x1E },   // 9 0x39  57
   { 0x00, 0x36, 0x36, 0x00, 0x00 },   // : 0x3A  58
   { 0x00, 0x56, 0x36, 0x00, 0x00 },   // ; 0x3B  59
   { 0x08, 0x14, 0x22, 0x41, 0x00 },   // < 0x3C  60
   { 0x14, 0x14, 0x14, 0x14, 0x14 },   // = 0x3D  61
   { 0x00, 0x41, 0x22, 0x14, 0x08 },   // > 0x3E  62
   { 0x02, 0x01, 0x51, 0x09, 0x06 },   // ? 0x3F  63
   { 0x3C, 0x42, 0x5A, 0x56, 0x0C },   // @ 0x40  64
   { 0x7E, 0x11, 0x11, 0x11, 0x7E },   // A 0x41  65
   { 0x7F, 0x49, 0x49, 0x49, 0x36 },   // B 0x42  66
   { 0x3E, 0x41, 0x41, 0x41, 0x22 },   // C 0x43  67
   { 0x7F, 0x41, 0x41, 0x22, 0x1C },   // D 0x44  68
   { 0x7F, 0x49, 0x49, 0x49, 0x41 },   // E 0x45  69
   { 0x7F, 0x09, 0x09, 0x09, 0x01 },   // F 0x46  70
   { 0x3E, 0x41, 0x49, 0x49, 0x7A },   // G 0x47  71
   { 0x7F, 0x08, 0x08, 0x08, 0x7F },   // H 0x48  72
   { 0x00, 0x41, 0x7F, 0x41, 0x00 },   // I 0x49  73
   { 0x20, 0x40, 0x41, 0x3F, 0x01 },   // J 0x4A  74
   { 0x7F, 0x08, 0x14, 0x22, 0x41 },   // K 0x4B  75
   { 0x7F, 0x40, 0x40, 0x40, 0x40 },   // L 0x4C  76
   { 0x7F, 0x02, 0x0C, 0x02, 0x7F },   // M 0x4D  77
   { 0x7F, 0x04, 0x08, 0x10, 0x7F },   // N 0x4E  78
   { 0x3E, 0x41, 0x41, 0x41, 0x3E },   // O 0x4F  79
   { 0x7F, 0x09, 0x09, 0x09, 0x06 },   // P 0x50  80
   { 0x3E, 0x41, 0x51, 0x21, 0x5E },   // Q 0x51  81
   { 0x7F, 0x09, 0x19, 0x29, 0x46 },   // R 0x52  82
   { 0x46, 0x49, 0x49, 0x49, 0x31 },   // S 0x53  83
   { 0x01, 0x01, 0x7F, 0x01, 0x01 },   // T 0x54  84
   { 0x3F, 0x40, 0x40, 0x40, 0x3F },   // U 0x55  85
   { 0x1F, 0x20, 0x40, 0x20, 0x1F },   // V 0x56  86
   { 0x3F, 0x40, 0x38, 0x40, 0x3F },   // W 0x57  87
   { 0x63, 0x14, 0x08, 0x14, 0x63 },   // X 0x58  88
   { 0x07, 0x08, 0x70, 0x08, 0x07 },   // Y 0x59  89
   { 0x61, 0x51, 0x49, 0x45, 0x43 },   // Z 0x5A  90
   { 0x00, 0x7F, 0x41, 0x41, 0x00 },   // [ 0x5B  91
   { 0x02, 0x04, 0x08, 0x10, 0x20 },   // \ 0x5C  92
   { 0x00, 0x41, 0x41, 0x7F, 0x00 },   // ] 0x5D  93
   { 0x04, 0x02, 0x01, 0x02, 0x04 },   // ^ 0x5E  94
   { 0x40, 0x40, 0x40, 0x40, 0x40 },   // _ 0x5F  95
   { 0x00, 0x01, 0x02, 0x04, 0x00 },   // ` 0x60  96
   { 0x20, 0x54, 0x54, 0x54, 0x78 },   // a 0x61  97
   { 0x7F, 0x48, 0x44, 0x44, 0x38 },   // b 0x62  98
   { 0x38, 0x44, 0x44, 0x44, 0x20 },   // c 0x63  99
   { 0x38, 0x44, 0x44, 0x48, 0x7F },   // d 0x64 100
   { 0x38, 0x54, 0x54, 0x54, 0x18 },   // e 0x65 101
   { 0x08, 0x7E, 0x09, 0x01, 0x02 },   // f 0x66 102
   { 0x0C, 0x52, 0x52, 0x52, 0x3E },   // g 0x67 103
   { 0x7F, 0x08, 0x04, 0x04, 0x78 },   // h 0x68 104
   { 0x00, 0x44, 0x7D, 0x40, 0x00 },   // i 0x69 105
   { 0x20, 0x40, 0x44, 0x3D, 0x00 },   // j 0x6A 106
   { 0x7F, 0x10, 0x28, 0x44, 0x00 },   // k 0x6B 107
   { 0x00, 0x41, 0x7F, 0x40, 0x00 },   // l 0x6C 108
   { 0x7C, 0x04, 0x18, 0x04, 0x78 },   // m 0x6D 109
   { 0x7C, 0x08, 0x04, 0x04, 0x78 },   // n 0x6E 110
   { 0x38, 0x44, 0x44, 0x44, 0x38 },   // o 0x6F 111
   { 0x7C, 0x14, 0x14, 0x14, 0x08 },   // p 0x70 112
   { 0x08, 0x14, 0x14, 0x18, 0x7C },   // q 0x71 113
   { 0x7C, 0x08, 0x04, 0x04, 0x08 },   // r 0x72 114
   { 0x48, 0x54, 0x54, 0x54, 0x20 },   // s 0x73 115
   { 0x04, 0x3F, 0x44, 0x40, 0x20 },   // t 0x74 116
   { 0x3C, 0x40, 0x40, 0x20, 0x7C },   // u 0x75 117
   { 0x1C, 0x20, 0x40, 0x20, 0x1C },   // v 0x76 118
   { 0x3C, 0x40, 0x30, 0x40, 0x3C },   // w 0x77 119
   { 0x44, 0x28, 0x10, 0x28, 0x44 },   // x 0x78 120
   { 0x0C, 0x50, 0x50, 0x50, 0x3C },   // y 0x79 121
   { 0x44, 0x64, 0x54, 0x4C, 0x44 },   // z 0x7A 122
   { 0x00, 0x08, 0x36, 0x41, 0x00 },   // { 0x7B 123
   { 0x00, 0x00, 0x7F, 0x00, 0x00 },   // | 0x7C 124
   { 0x00, 0x41, 0x36, 0x08, 0x00 },   // } 0x7D 125
   { 0x08, 0x04, 0x08, 0x10, 0x08 },   // ~ 0x7E 126

   { 0x40, 0x00, 0x40, 0x00, 0x40 },   // … 0x85 133
   { 0x04, 0x04, 0xFF, 0x04, 0x04 },   // † 0x86 134
   { 0x24, 0x24, 0xFF, 0x24, 0x24 },   // ‡ 0x87 135
   { 0x28, 0x7C, 0xAA, 0xAA, 0x82 },   // ˆ 0x88 136

   { 0x00, 0x06, 0x05, 0x00, 0x00 },   // ‘ 0x91 145
   { 0x00, 0x00, 0x05, 0x03, 0x00 },   // ’ 0x92 146
   { 0x06, 0x05, 0x00, 0x06, 0x05 },   // “ 0x93 147
   { 0x05, 0x03, 0x00, 0x05, 0x03 },   // ” 0x94 148
   { 0x18, 0x3C, 0x3C, 0x3C, 0x18 },   // • 0x95 149

   { 0x78, 0x48, 0x48, 0x78, 0x00 },   // ˜ 0x98 152

   { 0x22, 0x1C, 0x14, 0x1C, 0x22 },   // ¤ 0xA4 164
   { 0x7E, 0x02, 0x02, 0x02, 0x03 },   // ¥ 0xA5 165
   { 0x00, 0x00, 0xE7, 0x00, 0x00 },   // ¦ 0xA6 166
   { 0x4A, 0x95, 0xA5, 0xA9, 0x52 },   // § 0xA7 167
   { 0x7C, 0x55, 0x54, 0x45, 0x44 },   // ¨ 0xA8 168
   { 0x00, 0x18, 0x24, 0x24, 0x00 },   // © 0xA9 169
   { 0x3E, 0x49, 0x49, 0x41, 0x22 },   // ª 0xAA 170
   { 0x08, 0x14, 0x2A, 0x14, 0x22 },   // « 0xAB 171
   { 0x04, 0x04, 0x04, 0x04, 0x0C },   // ¬ 0xAC 172
   { 0x00, 0x08, 0x08, 0x08, 0x00 },   // ­ 0xAD 173

   { 0x00, 0x45, 0x7C, 0x45, 0x00 },   // ¯ 0xAF 175
   { 0x00, 0x04, 0x0A, 0x04, 0x00 },   // ° 0xB0 176
   { 0x44, 0x44, 0x5F, 0x44, 0x44 },   // ± 0xB1 177
   { 0x00, 0x41, 0x7F, 0x41, 0x00 },   // ² 0xB2 178
   { 0x00, 0x00, 0x7A, 0x00, 0x00 },   // ³ 0xB3 179
   { 0x00, 0x78, 0x08, 0x0C, 0x00 },   // ´ 0xB4 180
   { 0x00, 0xFC, 0x20, 0x3C, 0x20 },   // µ 0xB5 181
   { 0x0C, 0x1E, 0xFE, 0x02, 0xFE },   // ¶ 0xB6 182
   { 0x00, 0x18, 0x18, 0x00, 0x00 },   // · 0xB7 183
   { 0x39, 0x54, 0x54, 0x49, 0x00 },   // ¸ 0xB8 184
   { 0x78, 0x10, 0x20, 0x7B, 0x03 },   // ¹ 0xB9 185
   { 0x38, 0x54, 0x54, 0x44, 0x00 },   // º 0xBA 186
   { 0x22, 0x14, 0x2A, 0x14, 0x08 },   // » 0xBB 187

   { 0x00, 0x54, 0x70, 0x44, 0x00 },   // ¿ 0xBF 191
   { 0x7C, 0x12, 0x11, 0x12, 0x7C },   // À 0xC0 192
   { 0x7F, 0x49, 0x49, 0x49, 0x31 },   // Á 0xC1 193
   { 0x7F, 0x49, 0x49, 0x49, 0x36 },   // Â 0xC2 194
   { 0x7F, 0x01, 0x01, 0x01, 0x01 },   // Ă 0xC3 195
   { 0x60, 0x3F, 0x21, 0x3F, 0x60 },   // Ä 0xC4 196
   { 0x7F, 0x49, 0x49, 0x49, 0x41 },   // Å 0xC5 197
   { 0x77, 0x08, 0x7F, 0x08, 0x77 },   // Æ 0xC6 198
   { 0x22, 0x41, 0x49, 0x49, 0x36 },   // Ç 0xC7 199
   { 0x7F, 0x10, 0x08, 0x04, 0x7F },   // È 0xC8 200
   { 0x7E, 0x10, 0x09, 0x04, 0x7E },   // É 0xC9 201
   { 0x7F, 0x08, 0x14, 0x22, 0x41 },   // Ê 0xCA 202
   { 0x40, 0x3E, 0x01, 0x01, 0x7F },   // Ë 0xCB 203
   { 0x7F, 0x02, 0x0C, 0x02, 0x7F },   // ̀ 0xCC 204
   { 0x7F, 0x08, 0x08, 0x08, 0x7F },   // Í 0xCD 205
   { 0x3E, 0x41, 0x41, 0x41, 0x3E },   // Î 0xCE 206
   { 0x7F, 0x01, 0x01, 0x01, 0x7F },   // Ï 0xCF 207
   { 0x7F, 0x09, 0x09, 0x09, 0x06 },   // Đ 0xD0 208
   { 0x3E, 0x41, 0x41, 0x41, 0x22 },   // Ñ 0xD1 209
   { 0x01, 0x01, 0x7F, 0x01, 0x01 },   // ̉ 0xD2 210
   { 0x07, 0x48, 0x48, 0x48, 0x3F },   // Ó 0xD3 211
   { 0x0E, 0x11, 0x7F, 0x11, 0x0E },   // Ô 0xD4 212
   { 0x63, 0x14, 0x08, 0x14, 0x63 },   // Ơ 0xD5 213
   { 0x3F, 0x20, 0x20, 0x3F, 0x60 },   // Ö 0xD6 214
   { 0x07, 0x08, 0x08, 0x08, 0x7F },   // × 0xD7 215
   { 0x7F, 0x40, 0x7E, 0x40, 0x7F },   // Ø 0xD8 216
   { 0x3F, 0x20, 0x3F, 0x20, 0x7F },   // Ù 0xD9 217
   { 0x01, 0x7F, 0x48, 0x48, 0x30 },   // Ú 0xDA 218
   { 0x7F, 0x48, 0x30, 0x00, 0x7F },   // Û 0xDB 219
   { 0x00, 0x7F, 0x48, 0x48, 0x30 },   // Ü 0xDC 220
   { 0x22, 0x41, 0x49, 0x49, 0x3E },   // Ư 0xDD 221
   { 0x7F, 0x08, 0x3E, 0x41, 0x3E },   // ̃ 0xDE 222
   { 0x46, 0x29, 0x19, 0x09, 0x7F },   // ß 0xDF 223
   { 0x20, 0x54, 0x54, 0x54, 0x78 },   // à 0xE0 224
   { 0x3C, 0x4A, 0x4A, 0x4A, 0x31 },   // á 0xE1 225
   { 0x7C, 0x54, 0x54, 0x28, 0x00 },   // â 0xE2 226
   { 0x7C, 0x04, 0x04, 0x0C, 0x00 },   // ă 0xE3 227
   { 0x60, 0x3C, 0x24, 0x3C, 0x60 },   // ä 0xE4 228
   { 0x38, 0x54, 0x54, 0x54, 0x18 },   // å 0xE5 229
   { 0x6C, 0x10, 0x7C, 0x10, 0x6C },   // æ 0xE6 230
   { 0x00, 0x44, 0x54, 0x54, 0x28 },   // ç 0xE7 231
   { 0x7C, 0x20, 0x10, 0x08, 0x7C },   // è 0xE8 232
   { 0x7C, 0x21, 0x12, 0x09, 0x7C },   // é 0xE9 233
   { 0x7C, 0x10, 0x28, 0x44, 0x00 },   // ê 0xEA 234
   { 0x40, 0x38, 0x04, 0x04, 0x7C },   // ë 0xEB 235
   { 0x7C, 0x08, 0x10, 0x08, 0x7C },   // ́ 0xEC 236
   { 0x7C, 0x10, 0x10, 0x10, 0x7C },   // í 0xED 237
   { 0x38, 0x44, 0x44, 0x44, 0x38 },   // î 0xEE 238
   { 0x7C, 0x04, 0x04, 0x04, 0x7C },   // ï 0xEF 239
   { 0x7C, 0x14, 0x14, 0x14, 0x08 },   // đ 0xF0 240
   { 0x38, 0x44, 0x44, 0x44, 0x00 },   // ñ 0xF1 241
   { 0x04, 0x04, 0x7C, 0x04, 0x04 },   // ̣ 0xF2 242
   { 0x0C, 0x50, 0x50, 0x50, 0x3C },   // ó 0xF3 243
   { 0x08, 0x14, 0x7C, 0x14, 0x08 },   // ô 0xF4 244
   { 0x44, 0x28, 0x10, 0x28, 0x44 },   // ơ 0xF5 245
   { 0x3C, 0x20, 0x20, 0x3C, 0x60 },   // ö 0xF6 246
   { 0x0C, 0x10, 0x10, 0x10, 0x7C },   // ÷ 0xF7 247
   { 0x7C, 0x40, 0x7C, 0x40, 0x7C },   // ø 0xF8 248
   { 0x3C, 0x20, 0x3C, 0x20, 0x7C },   // ù 0xF9 249
   { 0x04, 0x7C, 0x50, 0x50, 0x20 },   // ú 0xFA 250
   { 0x7C, 0x50, 0x20, 0x00, 0x7C },   // û 0xFB 251
   { 0x00, 0x7C, 0x50, 0x50, 0x20 },   // ü 0xFC 252
   { 0x28, 0x44, 0x54, 0x54, 0x38 },   // ư 0xFD 253
   { 0x7C, 0x10, 0x38, 0x44, 0x38 },   // ₫ 0xFE 254
   { 0x48, 0x54, 0x34, 0x14, 0x7C }    // ÿ 0xFF 255
};

vvip-68, 2019-11-05:
Sorry, no. I have no free time for programming alien projects.
Try get piece of paper, pencil, write table of correspondence between ASCII code and index in yout fontHEX table, find a dependency and frite code. If you are not able to write smart program, do it in stupid way like:
if (ascii=0x20) return 0;
if (ascii=0x21) return 1;
and so further

tihoangyeudau, 2019-11-05:
Thank you. I will try to get it with your advice

Closed 2019-11-05.

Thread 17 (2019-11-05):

Приложение не конектитса никак

NazarDoeH, 2019-11-05:
Я сделал матрицу без датчика свіета и проигривателя сначала она нивкакую нехотела пото часов в 12 ночи я смог подключитса через ее точку доступа потом като (сам хз как) и по вайфаю
но ето било не долог всеволиш неделю теперь она опять нивкакую нехочет конектитма
помоги я незнаю штоделать

vvip-68, 2019-11-06:
Ну, если неделю работало, потом перестало, значит дело не в прошивке (прошивка то та же самая), а в аппаратной части. Например в телефоне. Похоже у него какие-то проблемы. Что за телефон? Подключатется ли с другого телефона? Подключается ли телефон к точке доступа? Есть ли эта точка доступа? Стабильное ли питание на микроконтроллере? Что пишет в мониторе порта? Вопросов - миллион.

NazarDoeH, 2019-11-06:
Телефон Xiaomi redmi note 4 .С другова непробивал.К самой точке подключаетса но ненадолго она потом одключаетса хотя сам модуль подключаетса к вайфаю и мает свой Айпи.Питание вроде норм ~5.10В подключил через стандартний бп.Нет Он стоял в одной и тойже розетке.Монитор порта пишит о подключении к вайфаю и айпи в нем ну и порт дальше он синхронитса з сервером но через какоето время он какби из еерома загружаетса но результат тотже

vvip-68, 2019-11-06:
Вот попробуйте все же с другого телефона. На стене были обсуждения, что точка падает, когда к ней с телефонов Xiaomi подключаются. Нсть подозрение, что у этих телефонов как-то не совсем корректно реализован сиек WiFi, и при несоблюдении протокола связи у ESP-шки просто сносит крышу и WiFi в ней падает до перезагрузки практически...

NazarDoeH, 2019-11-06:
И как ето решить у меня Мой телефон то Xiaomi уменя есть канешно и другие но они не мои

vvip-68, 2019-11-06:
Ну для начала попробовать - действительно ли это так.

NazarDoeH, 2019-11-06:
Ок спасибо попробою напишу

Closed 2019-11-07.

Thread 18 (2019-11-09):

speed of text is not working

tihoangyeudau, 2019-11-09:
When I was in the text section, I dragged the speed bar of the text to the right so the word didn't run faster.

Пейнтбол effect is can not be adjusted speed

When I turned off or turned on the demo mode, the wifi ip of led was disconnected and then not reconnected. But this error must be carefully tested so you can only see it appear

vvip-68, 2019-11-10:
Ok, thank you for report.
Speed text issue fixed on comment 10.11.2019 (last comment on this moment).
However I update esp8266 core on latest 2.6 version.
This version changed SerialSoftware class and changes are not compatiиду with usage SoftwareSerial in sketch. I tried to change it, but not sucesfully yet - matrich couldn`t read MP# player and report that it is absent :( Continue working on it.

Regarding speed settings for Пейнтбол (Paintball) effect. Effect is suggested by one of user. Implementation has not settings for this effect, it running on maxiamal speed. I managet to implement speed regulation, but not sucessfully. Used functions hardly depend on real time timers - beat8sin() of FastLed library. Attempt to tune speed lead to drawing effect not smoothly.
So, I couldnt implement settings for speed. Currently speed trackbarg select variation of effect - 1,2,3 or 4 balls moving over the screen. Probably will implement at next attempts.

Didn`t understand about last issue with connection.
However I discovered that A0 analog input is internally used by WiFi part of MCU for some internal meassures. So, If you not physically have photoresistor connected to A0, call of analogRead() may cause tamper internal usage of WiFi measure and mcu may torn WiFi off.
In the last version of sketch I added define for USE_PHOTO. If you does not have photoresistor set USE_PHOTO to 0. This will avoid use analogRead() part of code that may protect WiFi from crash

Closed 2019-11-11.

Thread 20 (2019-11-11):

Зеркальное отображение

depoid, 2019-11-11:
Хотелось бы реализацию настройки в приложении для зеркального отображения.
Например, если есть гирлянда в окне, чтобы можно было развернуть изображение наружу или внутрь.

vvip-68, 2019-11-11:
Это все регулируется настройками угла подключения и направления ленты
Также, возможно, что-то получится с текстом, если поиграться настройками
#define MIRR_V 0          // отразить текст по вертикали (0 / 1)
#define MIRR_H 0          // отразить текст по горизонтали (0 / 1)
в runningText.ino

depoid, 2019-11-11:
Про настройки прошивки все понятно.
Я имел ввиду зеркалирование во время работы устройства.
Сейчас же надо перепрошивать контроллер.
Добавить всего 1 чекбокс в приложение :)

Closed 2019-11-11.

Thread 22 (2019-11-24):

narodmon

NLObP, 2019-11-24:
Привет vvip-68! Помоги добавить в бегущую строку температуру с сайта narodmon.ru. У них в справке есть описание как добавить в приложения, на сайт... У меня есть кое-какие наброски, не получается внедрить. Нули показывает, так-как текст для строк пишется в setup.

vvip-68, 2019-11-25:
Я на заказ не делаю. Это тебе или самому разбираться - тем более все расписано, говоришь. Или в "ищу разработчика".

Closed 2019-11-25.

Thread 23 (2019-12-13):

Проблема направлением бегущей строки текста при отзеркаливании

ameth-cmd, 2019-12-13:
Столкнулся с такой проблемой:

Собираю матрицу "на окне", "лицом" к себе, т.е. говоря словами прошивки -

#define MATRIX_TYPE 0
#define CONNECTION_ANGLE 0
#define STRIP_DIRECTION 1
Сама матрица нанесена на окно с его левого нижнего угла в правый и далее зигзагом.

Т.е. вот так: https://prnt.sc/qa4dg9

По-умолчанию, текст выводится так, чтобы его было видно "из квартиры", т.е. стоя "лицом" к матрице.
Бегущая строка при этом идет из правого угла в левый, буквы в "нормальном" виде, т.е. глядя из кваритры - все ок, глядя из улицы - текст "отзеркален" и идет "не в ту сторону".

Т.е. вид изнутри квартиры: http://prntscr.com/qa4dml

Вид с улицы: http://prntscr.com/qa4dqc

В настройках прошивки конечно же есть параметр

#define MIRR_V 1 - и в таком случае буквы "отзеркаливаются" и их видно "правильными" со стороны улицы.

Но направление текста при этом не меняется, и с точки зрения зрителя с улицы оно идет из левого угла в правый, хоть и буквы
при этом выглядят правильно.

 Т.е. вот так: http://prntscr.com/qa4dtg

Можно ли как-то поменять направление текста, чтобы он шел "из правого угла в левый" для зрителя из улицы, т.е. того, к которому матрица повернута "изнанкой"?

vvip-68, 2019-12-16:
Не надо ничего делать с MIRR_V 1 Это не для этого. Это именно для отражения в зеркале.
Чтобы бегущая строка правильно читалась с улицы - задайте правильно угол подключения и направление матрицы. То есть не с точки зрения как оно смотрится из квартиры, а так Как вы бы смотрели на матрицу с улицы.  В вашем случае это будет
направление с его правого нижнего угла в левый и далее зигзагом.

Closed 2019-12-16.

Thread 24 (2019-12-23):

TimeZone need edit 2 times (2 different places)

AlexxVel, 2019-12-23:
У меня телефон с Android 4.2  Установить на него приложение GyverMatrixWiFi.apk я не могу (т.к. там минимальная версия API 19, т.е. Android 4.4). Из-за невозможности установить и использовать приложение, столкнулся с проблемой неправильного вывода времени на матрицу (виновница - timeZoneOffset). Как оказалось - недостаточно только отредактировать строку 453 в файле GyverMatrixOS_v1.15.ino:  int8_t timeZoneOffset = 3;  (выставить свою таймзону).
необходимо также отредактировать строку 168 в eeprom.ino :
timeZoneOffset = 3;
Что несколько неудобно (и начинающие пользователи, не разбирающиеся в коде, будут в затруднительном положении...)

vvip-68, 2019-12-24:
Да, спасибо. Убрал из eeprom.ino

Closed 2019-12-24.

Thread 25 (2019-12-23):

Ntp сервер, что я делаю не так

igorpats, 2019-12-23:
Никак не могу настроить синхронизацию с ntp сервером. Проблема в следующем:
22:36:02.254 -> NTP-сервер www.belgim.by -> 178.124.164.107
22:36:02.254 -> Отправка NTP пакета на сервер www.belgim.by
22:36:07.075 -> UDP пакeт размером 6 от 192.168.1.218, порт 2390
22:36:07.075 -> Содержимое: $18 0;
22:36:07.244 -> Таймаут NTP запроса!
И так постоянно какой-бы адрес не указывал. Не могу понять почему оно пакеты не принимает от сервера. Порт использовал 123 как в исходнике. Пробовал и другие.

vvip-68, 2019-12-24:
Скорее всего у вас на роутере или у провайдера закрыт 123 порт и пакеты запроса к серверу не уходят. Что, например, говорит Windows при попытке синхронизировать его время с сервером ntp? Можно поискать для теста стороннюю программу на комп - синхронизатор времени NTP. Работает ли он? Что сообщает?
Другие порты использовать бесполезно. 123 порт - стандартный порт сервиса синхронизации времени. Если сервера времени специально админы на другой порт не переносят. А такого практически не бывает, ибо стандарт.
Проверьте работу синхронизации времени на компе. Если в вашей сети она не работает (заблокирована) - смотрите нет ли запрета в настройках роутера и/или пишите письмо админу, пусть разбирается.

igorpats, 2019-12-24:
Windows 7 на вкладке синхронизация времени по интернету делает это без вопросов с любым рабочим сервером. Вот к примеру использовал стороннюю ntpquerty и в бил туда ip из вашего списка.
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  Пытался смотреть переменные через монитор порта, никогда не получаю ничего в ответ на запрос.

vvip-68, 2019-12-24:
Ну, тогда у меня нет ответа. Вы единственный из сотен собравших у кого это не работает.
Если найдете, что причина все же в скетче - сообщите, исправим. По логике кода я проблем не вижу. Повторить ошибку  не могу. Исправить, следовательно, тоже. С моей точки зрения там нечему не работать.

igorpats, 2019-12-24:
Вот странно, прошу людей скинуть лог с монитора порта, где видно что работает, так никто и не может. Я бы и сам не полез если бы затыков не было после определенной серии неудачных подключений (wifi переподключает).  Попробую прошивку с лампы с готовой библиотекой ntp запустить и посмотреть что происходит.

vvip-68, 2019-12-24:
Ну, вот что выводит сразу при включении:
18:21:43.358 -> ....
18:21:45.669 -> WiFi подключен. IP адрес: 192.168.0.96
18:21:45.703 ->
18:21:45.703 -> UDP-сервер на порту 2390
18:21:45.703 -> Инициализация MP3 плеера...
18:21:46.151 -> Звуков будильника найдено: 2
18:21:46.151 -> Звуков рассвета найдено: 6
18:21:46.151 -> Включен эффект 'Радужные переливы'
18:21:46.151 -> NTP-сервер ru.pool.ntp.org -> 192.36.143.130
18:21:46.151 -> Отправка NTP пакета на сервер ru.pool.ntp.org
18:21:46.252 -> UDP пакeт размером 48 от 192.36.143.130, порт 123
18:21:46.252 -> Разбор пакета NTP
18:21:46.252 -> Секунд с 1970: 1577211705

Так если мешает перезагрузка сети при 10 неудачных попытках синхронизации - просто убери эту строчку из скетча

igorpats, 2019-12-24:
нет, не редактировал. Специально из архива вытаскивал и менял перед опытами. А никаких изменений не вносилось с предыдущих версий. Я просто не помню раньше затыков при включенной синхронизации с ntp. Можно просто в режиме точки доступа использовать для управления.
Попробую сегодня покрутить настройки роутера по поводу 123 порта.

vvip-68, 2019-12-24:
Постоянно что-то вносится в версии. На то и смена. Но касательно именно работы с NTP не менялось ничего. Как в версии 1.12 было - так все и осталось. Если тебе не нужна синхронизация (или она вот так вот не работает) - просто выключи ее из приложения - там галочка есть "Использовать синхронизацию с NTP" в настройках часов.

igorpats, 2019-12-24:
Спасибо, так и делал. Для примера поставил последнюю прошивку с лампы, там библиотека ntp есть. Добавил вывод времени в
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
порт, показывает корректно, значит оно работает.

igorpats, 2019-12-24:
Поставил голую прошивку только поменял ssid и пароль сети и залил. Ничего не трогал вообще
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 Тоже самое. Версия ядра 2.6.1

igorpats, 2019-12-24:
Что-то мне кажется что это с портами связанно. У моего провайдера динамический ip, спрятанный за natoм. Вариантов получить белый ip почти нет. Буду побывать долбить их.

vvip-68, 2019-12-25:
Вряд ли с портами. 123 порт - стандарт для NTP;
У меня тоже не белый IP - но работает же почему-то.
Или нет? Затык может быть в строчке (которая на прежних ядрах точно работала!)
WiFi.hostByName(ntpServerName, timeServerIP);
Потому что IP по которому идет запрос - 192.36.143.130 - аварийный, когда не удается преобразовать имя хоста в IP. Но у меня этот IP откликается, а у вас видимо нет.
Когда оно работало - получался каждый раз разный IP сервера из их пула.
Попробуйте хотя бы на компе несколько раз подряд выполнить ping ru.pool.ntp.org
Каждый раз практически разные IP выдаются. А тут всегда аварийный используется...
Надо посмотреть внимательнее этот момент...

igorpats, 2019-12-25:
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
Пингуется всегда с одним адресом
Вот если вбить просто pool.ntp.org
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
Уже другой адрес что естественно.
Ниже фото что win синхронизирует время с обоими серверами
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
Просто по 123 порту ничего не идет, и в DMZ добавлял свой ip. Глухо
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

igorpats, 2019-12-25:
Делаю тоже самое через 123 порт:
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

igorpats, 2019-12-25:
Порт закрыт, любой адрес через 123 не откликается

vvip-68, 2019-12-25:
Я бы не стал верить винде, что она синхронизировалась. Те еще пройдохи.
Как она синхронизируется? Не через 123 порт? У нее свое что-то?
Ну если 123 порт закрыт (где? На роутере? у провайдера?) так синхронизация и не будет работать... Провайдеру письмо написать - что ответит?

igorpats, 2019-12-25:
у нас он монополист, ничего отвечать не будет. не хочешь не пользуйся. Буду побывать что-то с провайдером сделать. Порт из вне закрыт как я понимаю

vvip-68, 2019-12-25:
А как утилита, что вы выше приводили синхронизируется? Ей то можно верить. И она, вроде как, тоже по 123 порту работает.

igorpats, 2019-12-25:
Какая утилита? port cheker просто порты проверяет

vvip-68, 2019-12-25:
NtpQuery. Где-то в самом верху ветки

AlexxVel, 2019-12-25:
Позавчера тоже имел проблемы с получением времени по NTP. Версия платформы esp8266 2.6.3
Изначально сменил #define DEFAULT_NTP_SERVER "pool.ntp.org" // было "ru.pool.ntp.org"

WiFi.hostByName(ntpServerName, timeServerIP); - функция не отрабатывает и идет на "аварийный" IP. Я его сменил на тот, который у меня DNS-сился из коммандной строки (вроде начинался на 5.32.x.x - сейчас нет возможности посмотреть, т.к. не дома )  прямо в прошивке
#if defined(ESP8266)
  if (!timeServerIP.isSet()) timeServerIP.fromString(F("5.32.x.y"));  // тут было 192.36.143.130
#endif
После этого все заработало...

igorpats, 2019-12-25:
ntpquerty неизвестно как работает, но если сервер рабочий, оно данные получает

igorpats, 2019-12-25:
Alex, вы сменили на тот адрес по которому отозвался pool.ntp.org?

AlexxVel, 2019-12-25:
да

AlexxVel, 2019-12-25:
в командной строке набрал ping pool.ntp.org
IP оттуда вписал в clock.ino в 84-ю строку. Перекомпилил и загрузил в wemos d1. И все заработало.

igorpats, 2019-12-25:
я побывал играться с локальными серверами по вашей методике.
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
не получалось, попробую еще, спасибо
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
AlexxVel, 2019-12-31:
У меня на основе 15-й версии. Сделал поиск по коду - параметры FASTLED_INTERRUPT_RETRY_COUNT и FASTLED_ALLOW_INTERRUPTS дефайнами в коде не определены. Соответственно исходя из led_sysdefs_esp8266.h получаем
#ifndef FASTLED_ALLOW_INTERRUPTS
# define FASTLED_ALLOW_INTERRUPTS 1
# define INTERRUPT_THRESHOLD 0
#endif
а исходя из кода fastled_config.h
#ifndef FASTLED_INTERRUPT_RETRY_COUNT
#define FASTLED_INTERRUPT_RETRY_COUNT 2
#endif

fsb054c, 2019-12-31:
Алекс, спасибо за код.

По дефайнам все так. На 15 версии у меня нормально работает только с нулями.

Такие же параметры в GyverLamp_v1.5.5 (и ранее), которая не фликерит. Это и навело на мысль, что дело чисто в софте, а не в железе.

AlexxVel, 2019-12-31:
Немного причесал код (вместо 4-х функций: WriteDays,WriteMinutes,WriteHours,WriteSeconds сделал одну WriteVremOtr, остальное как 3 поста назад):
```
static const String NamesVrem1[4] = { " ДНЕЙ", " ЧАСОВ", " МИНУТ", " СЕКУНД"};
static const String NamesVrem2[4] = { " ДЕНЬ", " ЧАС", " МИНУТА", " СЕКУНДА"};
static const String NamesVrem3[4] = { " ДНЯ", " ЧАСА", " МИНУТЫ", " СЕКУНДЫ"};

String WriteVremOtr(int iVrOtr, byte typeVrOtr){
  if ((iVrOtr >= 5) && (iVrOtr <= 20)) return NamesVrem1[typeVrOtr];
  else {
    iVrOtr = iVrOtr %10;
    if (iVrOtr == 1) return NamesVrem2[typeVrOtr];
    else if ((iVrOtr >= 2) && (iVrOtr <=4)) return NamesVrem3[typeVrOtr];
    else return NamesVrem1[typeVrOtr];
  }
}

String DO_NY = "ДО НОВОГО ГОДА ОСТАЛОСЬ - ";
String WriteCounter(unsigned long tsCurRemained){
  int iDays = tsCurRemained/(24*3600);
  int iHours = tsCurRemained/3600;
  int iMinutes = tsCurRemained/60;
  int iSeconds = tsCurRemained;

  if (iDays > 1) return DO_NY + String(iDays,DEC) + WriteVremOtr(iDays,0);
  else {
    if (iHours >= 1) return DO_NY + String(iHours,DEC) + WriteVremOtr(iHours,1);
    else {
      if (iMinutes >= 1)return DO_NY + String(iMinutes,DEC) + WriteVremOtr(iMinutes,2);
      else {
        if (iSeconds > 1)return DO_NY + String(iSeconds,DEC) + WriteVremOtr(iSeconds,3);
        else {
          return String("С НОВЫМ ГОДОМ!!!");
        }
      }
    }
  }
}

```

fsb054c, 2019-12-31:
Алекс, а фликеринг пропал? Помогло?

AlexxVel, 2019-12-31:
Пока за окном еще светло. Через полчаса буду пробовать...

ACKET2009, 2019-12-31:
Ребят, может перезальёте скетчи поправленные? У нас уже время - пора бокалы наливать :) Но ещё успеваем

fsb054c, 2019-12-31:
Я подправил вот так
```
String WriteCounter(unsigned long tsCurRemained){
  int iDays = tsCurRemained/(24*3600);
  int iHours = tsCurRemained/3600;
  int iMinutes = tsCurRemained/60;
  int iSeconds = tsCurRemained;

  if (iDays > 1) return DO_NY + String(iDays,DEC) + WriteVremOtr(iDays,0) + ", " + String(iHours,DEC) + WriteVremOtr(iHours,1) + ", " + String(iMinutes,DEC) + WriteVremOtr(iMinutes,2) + ", "  + String(iSeconds,DEC) + WriteVremOtr(iSeconds,3);
  else {
    if (iHours >= 1) return DO_NY + String(iHours,DEC) + WriteVremOtr(iHours,1) + ", " + String(iMinutes,DEC) + WriteVremOtr(iMinutes,2) + ", "  + String(iSeconds,DEC) + WriteVremOtr(iSeconds,3);
    else {
      if (iMinutes >= 1)return DO_NY + String(iMinutes,DEC) + WriteVremOtr(iMinutes,2) + ", "  + String(iSeconds,DEC) + WriteVremOtr(iSeconds,3);
      else {
        if (iSeconds > 1)return DO_NY  + String(iSeconds,DEC) + WriteVremOtr(iSeconds,3);
        else {
          return String("С НОВЫМ ГОДОМ!!!");
        }
      }
    }
  }
}
```

Получаются бегущие часы, минуты и секунды уменьшающиеся в процессе движения

Еще в setRandomMode2() сделал после byte newMode = random(0, MODES_AMOUNT - 1);" вставку
```
    byte counterToNY = random(0, 2);
    if (counterToNY==0) newMode=DEMO_TEXT_2;
```
что бы увеличить вероятность выпадения этого режима.

Как времянка для эвента до НГ подойдет :-)

AlexxVel, 2019-12-31:
Сделал
#define FASTLED_INTERRUPT_RETRY_COUNT 0
#define FASTLED_ALLOW_INTERRUPTS 0
до подключения #include "FastLED.h"
Такое ощущение, что артефактов стало еще больше. Даже стены в игре Лабиринт теперь иногда моргают красным...

fsb054c, 2019-12-31:
У меня так же переопределено до всех инклюдов.
Печаль, значит возможно этимология проблемы разная у нас.

igorpats, 2019-12-31:
У меня при отсчете выводит просто дату текущую, что-то я не то делаю

AlexxVel, 2019-12-31:
Опять избавился от артефактов. Не знаю, надолго-ли... Понизил питание на ленту с 5.01В
 до 4.3В за счет установки советского выпрямительного диода, рассчитанного на ток 5А)
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

ant1xr1st87, 2020-01-04:
> Опять избавился от артефактов. Не знаю, надолго-ли... Понизил питание на ленту с 5.01В
> до 4.3В за счет установки советского выпрямительного диода, рассчитанного на ток 5А)
> 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

Почему то сразу вспомнил пост с Пикабу про заземление😁😁😁

Closed 2019-12-24.

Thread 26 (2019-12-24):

Режимы по времени

ACKET2009, 2019-12-24:
Здравствуйте! Сделал себе на окно вместо новогодней шторы - слов нет, потрясающе работает!! Есть 2 момента - если не отключать игру в лабиринт, регулярно подвисает на ней а то и перезапускается. В остальном никаких ошибок не обнаружил. А по второму - есть всего 2 режима по времени, то есть можно поставить время включения и время выключения. С точки зрения применения такой штуки на окне было бы логично добавить ещё 2 режима. Днём огоньков почти не видно и смысла зажигать гирлянду нет, поэтому хотелось бы, чтобы включалась вечером, когда темнеет и выключалась, когда поздно совсем, затем снова включалась в утренние часы пока темно и выключалась с рассветом... Если это не сложно, конечно, в приложении как раз пол страницы с режимами по времени пустые, а добавить 2 пункта и будет красота! :) А, вот ещё забыл - для деморежима есть 3 надписи бегущих строки, их как-то можно вынести в приложение на телефоне, чтобы можно было менять без перепрошивки?

vvip-68, 2019-12-24:
Все это можно. Но нужно переделывать и прошивку и программу.
По трем строкам, задаваемым в приложении - вот-вот уже собирался, но так руки и не дошли.
По еще двум режимам - теоретически можно, практически - приложение в конструкторе и так уже еле шевелится. Очень некомфортно там что-то переделывать.
Резюме - может быть когда-нибудь. Не последний же Новый год...

ACKET2009, 2019-12-25:
Да, пробовал я в конструкторе на сайте просто посмотреть как и что делается - нереально тормозит... я думал это мой компьютер предпенсионного возраста... Да, там всё туго...

Closed 2019-12-24.

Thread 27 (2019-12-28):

Включение по расписанию

Dante6214, 2019-12-28:
Приветствую. Настроил включение-выключение по времени. Но, включена матрица была в демо режиме с автосменой эффектов, потом выключается, а включается в следующий раз всегда в ручном режиме. Причем не важно какая цифра стоит в поле "авторежим через" сам авторежим не включается. Только вручную каждый раз.

vvip-68, 2019-12-29:
Ничё не понял.  У меня полгода уже - в 23 выключить (или в ночные часы), в 8 утра - случайный режим - то есть демо/автосмена. Всё работает. Если вы указываете при включении конкретный режим - ну так он и включится и будет в нем как в "ручном" режиме работать. Что не так то?

Dante6214, 2019-12-29:
Ну да, конкретный стоит. Думал что если стоит цифра в "авторежим через" то через н-ное число должен включиться авторежим со сменой. Попробовал "случайный эффект", да, действительно, так работает

Closed 2019-12-29.

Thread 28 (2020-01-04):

apk

hediondo1, 2020-01-04:
possible english android apk?

ant1xr1st87, 2020-01-04:
Учите русский! Знание десятка русских слов не повредит.

vvip-68, 2020-01-10:
It`s impossible. Nobody to do that. If you have an account in Thunkable Classic, you may make english version yourself. Code is open.

Closed 2020-01-10.

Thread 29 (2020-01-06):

Прошу помочь!!

Kkastiel, 2020-01-06:
Привет. Не подключается с приложки к плате, что делать? Телефон Xiaomi. Точка доступа WiFi есть, но называется не MatrixAP(как у Гивера на видео), а FireLink_513DC6. К точке подключается и само не отключается. Плата WeMos D1 R1.  Прошито как надо.
Но.. в приложении тупо не подключается.

Closed 2020-01-06.

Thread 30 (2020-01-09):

Не работает синхронизация времени

LaMarmota, 2020-01-09:
NTP-сервер ru.pool.ntp.org -> 192.36.143.130
Отправка NTP пакета на сервер ru.pool.ntp.org
Таймаут NTP запроса!

И так постоянно... Пробовал разные платы (NodeMCU, Wemos). WiFi подключается и работает нормально.
В чем может быть проблема?

vvip-68, 2020-01-09:
Судя по приведенному выше сообщению - у вас устаревшая версия прошивки.
Синхронизация может также не работать по причине того, что ваш провайдер закрыл порт по которому получаются NTP пакеты (123); может быть в настройках роутера что-то заблокировано.

LaMarmota, 2020-01-09:
Прошивку скачивал последнюю отсюда. Библиотеки все скопировал. Порты точно не закрыты. Есть еще варианты в чем может быть дело?

vvip-68, 2020-01-09:
Других вариантов нет.
1. Тут кто-то уже писал про эту проблему. Именно после обсуждения было предложено изменить процедуру подключения к сети - использовать вариант инициализации с указанием IP DNS серверов. После изменения проблема решилась.
2. Судя по тому какой вывод вы привели выше - У ВАС СТАРАЯ ВЕРСИЯ, в которых этих изменений нет.
3. Тут кто-то уже писал (по поводу другой проблемы, правда) - "я скачал отсюда последнюю версию - там нет того-то и того-то". Пока носом не ткнул в текст скетча прям тут на GITe в файл, что все изменения есть и сделаны еще месяц назад, утверждал что у него последняя версия скачана. Потом все же как-то скачал действительно последнюю версию и его проблема исчезла. Проверьте еще раз - действительно ли у вас последняя версия, со всеми исправлениями.

Closed 2020-01-09.

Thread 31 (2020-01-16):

управление через MQTT?

alekseyn1, 2020-01-16:
Здравствуйте,
Возможно ли соединить Ваш проект по упраляемой по MQTT матрице с этим проектом?
Цель: передавать бегущую строку и переключать режимы через Home Assistant (работающий на MQTT)
Заранее благодарю за ответ.
Алексей

vvip-68, 2020-01-17:
Вполне возможно. Код открыт. Делайте форк проекта и добавляйте управление через MQTT.

Closed 2020-01-17.

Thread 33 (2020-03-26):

WiFi Password

thealexmade, 2020-03-26:
В программе длинна пароля на WiFi точку ограничина 16 символами. А можно как то увеличить до 24 хотя бы? у меня пароль длинней и я не могу подключить ее к своему роутеру :(

thealexmade, 2020-04-02:
хай, там можете добавить длинну пароля больше 16 символов?

thealexmade, 2020-04-11:
В итоге сделал сам. Вообще заменил длинну переменных (они встречаются в нескольких закладках кода)
char ssid[17] = "";                  // SSID (имя) вашего роутера (конфигурируется подключением через точку доступа и сохранением в EEPROM) (было 25)
char pass[25] = "";

str.toCharArray(ssid, 16); //было 24
str.toCharArray(pass, 24); // было 16

 getSsid().toCharArray(ssid, 17);                //  80-103  - имя сети  WiFi       (24 байта макс) + 1 байт '\0' (БЫЛО 25)
    getPass().toCharArray(pass, 25);                //  104-119 - пароль сети  WiFi    (16 байт макс) + 1 байт '\0'   (БЫЛО 17)

return EEPROM_string_read(46, 16);
  return EEPROM_string_read(46, 16);
    EEPROM_string_write(46, Ssid, 16);
  return EEPROM_string_read(62, 24);
    EEPROM_string_write(62, Pass, 24);

Closed 2020-04-11.

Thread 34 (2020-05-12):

температура

zveronline, 2020-05-12:
Нет ли простого способа вывести температуру рядом с часами, с датчика через homeassistant?

vvip-68, 2020-07-27:
Ну, если написать соответствующий функционал - можно всё что угодно. Пишите.

Closed 2020-07-27.

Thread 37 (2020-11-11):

Матрица

Craimerix, 2020-11-11:
Привет. Очень понравилась твоя прошивка и приложение, но такое вопрос: собрал я к примеру рюкзак по видео Гайвера, перепаивать схему не очень хочется. Можно ли загрузить просто твою прошивку? Будет ли оно работать без дополнительных элементов?

vvip-68, 2020-11-14:
Можно. Будет. Если не перепаивать - возможно в прошивке потребуется скорректировать пин на ленту. Сейчас D2 - я не помню куда подключен в рюкзаке.
А не проще было просто взять и попробовать?

Closed 2020-11-14.

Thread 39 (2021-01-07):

Матрица 27х6 nodemcu не отображаются часы на фоне эффектов что я делаю не так?

tribunskiysm, 2021-01-07:
У меня матрица 27х6 nodemcu не отображаются часы поверх эффекта что я делаю не так?
Что может быть нетак. В программе невозможно выбрать эффект Часы, при его выборе автоматически включается другой эффект - звездопад.
В программе WiFi Matrix в разделе Текст - сообщение что Размеры матрицы недостаточны но текст отображается немного подрезанным снизу - можно ли както уменьшить шрифт разблокировать этот раздел в программе?
Хотелось использовать матрицу как часы с бегущей строкой, очень хорошо работают игры runner и змейка)

vvip-68, 2021-01-07:
Чаcы: для часов в этом проекте требуется минимум 7 строк текста. Почему - не помню. Попробуйте в основном файле в строке 257 проверку исправить с 7 до 5. Может быть часы заработают, может быть будут отображаться "криво".

Текст: ну ясно же написано - размер матрицы недостаточный. Делайте хотя бы 8 строк. Это минимум для бегущей строки.
Для уменьшения шрифта - берете листок в клеточку и пытаетесь нарисовать буквы высотой в 6 точек. Нли получится - идете в файл fonts.h и переписываете там образы букв с высоты 8 на ваши высотой 6. Далее в runningText.ino переписываете процедуру drawLetter и все что она вызывает так, чтобы они работали с буквами не 8 точек, а нарисованными вами 6-точечными.

tribunskiysm, 2021-01-07:
Спасибо буду пробовать. С часами разобрался в программе выкручиваю яркость до нуля и они отображаются правда очень тускло приэтом на фоне эфекты пропадают почиму это происходит пока неразобрался..

Closed 2021-01-07.

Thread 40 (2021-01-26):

Проблема с приложением PanelWifi

Mija-ops, 2021-01-26:
Не происходит подключение по wifi со смартфона.
Опишу свои действия по шагам.
1) Подключился к точке доступа, который раздал esp8266
2) В настройках прописал имя сети, пароль и присвоил ip, устройство отключило точку доступа, в роутере появилось новое устройство с заданным ранее ip ( подсеть правильная, остальные устройство такие же
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
3)С компьютера все пингуется
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

4) Пробую уже по этому ip подключиться в приложении WiFiPanel. Не подключается
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

В роутере отключения изоляция клиентов
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

Телефон: Xiaomi Mi Mix 2s
Роутер  Xiaomi Mi WiFi Router 4A GIGABIT с кастомной прошивкой Padavan

vvip-68, 2021-01-26:
Добейтесь, чтобы пинговалось не только с компьютера, но и с телефона на котором установлено приложение. Как только с телефона (из приложения) пакеты начнут доходить до контроллера - соединение установиться.

Mija-ops, 2021-01-26:
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

А как этого добиться, если, уверен что и телефон и устройство находятся в одной подсети? Тогда вероятнее всего проблема в настройках роутер?

vvip-68, 2021-01-26:
Я не знаю. С этим вопросов вам, вероятно, лучше обратиться в профильные форумы по сетевым настройкам и роутерам вообще и по данной модели роутера в частности.

Mija-ops, 2021-01-26:
> Добейтесь, чтобы пинговалось не только с компьютера, но и с телефона на котором установлено приложение. Как только с телефона (из приложения) пакеты начнут доходить до контроллера - соединение установится.

Я удостоверился в том, что с телефона все пингуется в сторону устройства и пакеты доходят
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

Mija-ops, 2021-01-26:
@vvip-68
И что интересно, у устройства не открыт порт 2390( который по умолчанию
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

vvip-68, 2021-01-26:
Ну, попробуйте перепрошить контроллер с включенной опцией "Erase all" и заново все настроить.
Порт задается константой в скетче и насколько я помню это значение нигде не меняется.
У меня нет ответа почему в вашем случае порт не открыт.
Обновите версию ядра до актуальной, если это не так.
Вообще, странно обсуждать проект WiFiPanel в issues проекта WiFiMatrix...

vvip-68, 2021-01-26:
А вы уверены, что телнетом можно подключиться?
У меня тоже телнет выдает ошибку подключения, однако приложение - соединяется.
Так что - это не показатель.

Closed 2021-01-26.

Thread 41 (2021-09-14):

Annoying Pixel Dot

TimoUrban, 2021-09-14:
Hi!
I tried to get this project running with a 16x16 pixel matrix powered by NodeMCU.

I compiled the software with lots of different variations of the ESP Board-Libary and the FastLED Libary but in any way I get an annoying first pixel dot in the bottom left corner.
It depends on the libaries I used if its green, blue, pink, flashing or static.

Picture: https://ibb.co/0hMYh2X

(I know, this project is outdated but I really wanted to get rid of this pixel, beacause I still running into trouble with the Android app when I am using the GyverPanel Code)

vvip-68, 2021-09-14:
Hi,
do not use ESP8266 core version V3.x.x → it lead to issue you described.
Set ESP8266 core version 2.7.4 and rebuild project. It will solve the issue.
 
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
 
 
С уважением,
Вадим Пузанов
 

TimoUrban, 2021-09-14:
Thank you for your fast repl!

I tried using the ESP8266 core version 2.7.4. and the matrix will not start.
Tested it just now again and it won´t work.

Issue: https://ibb.co/MV6tVzq
Board config: https://ibb.co/tYQbG73

At the moment using FastLED verion 3.3.3. (I played around a lot with different versions)

TimoUrban, 2021-09-14:
I found out that every ESP 8266 core version below 3.0.0. is causing the same issue - the matrix is showing nothing expect the dot I don´t want to have hahaha

TimoUrban, 2021-09-14:
The next surprising fact: Depending on the number of demo page sometime the dot is gone:

https://www.youtube.com/watch?v=_8l6tKloZJo

vvip-68, 2021-09-14:
When you have definition 
#define LED_PIN  2     → core v3.x.x direct matrix signal to pin D4
When you have sme definition and core 2.7.4 signal directed to pin D2
 
Check that you have core v2.7.4 and signal pin connected to matrix is D2 (not D4)!
 

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
 
 
С уважением,
Вадим Пузанов
 

vvip-68, 2021-09-14:
Othervise you may use definition as
#define LED_PIN  **D**2 -> this direct output signal on 2.7.4 into pin D4

Which issue do you have with android application in GyverPanel project?

vvip-68, 2021-09-14:
Note, you MUST select mcu as 'NodeMCU v1.0' in IDE settings even you use really Wemos board instead of real NodeMCU

TimoUrban, 2021-09-14:
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

Holy cow, I feel so dumb now! My data pin was connected to PIN D4 on the NodeMCU. Switched to PIN D2 and uploaded the script with esp8266 core version 2.7.4 solved my problem.
I swear, I read your instructions over ten times, trying to find the error.
Buddy you saved my evening :-)

TimoUrban, 2021-09-14:
> Which issue do you have with android application in GyverPanel project?
When I install the script on the NodeMCU and connect the Android App to the panel, my inputs are going crazy. When I try to select an effect the list of effects is scrolling really fast.
Image uploads and drawing by hand is absolutely not working.

vvip-68, 2021-09-14:
Thank you for support my project.
I recived your ‘thanks’ over PayPal :)
 

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
Holy cow, I feel so dumb now! My data pin was connected to PIN D4 on the NodeMCU. Switched to PIN D2 and uploaded the script with esp8266 core version 2.7.4 solved my problem.
I swear, I read your instructions over ten times, trying to find the error.
Buddy you saved my evening :-)
—
You are receiving this because you commented.
Reply to this email directly,  view it on GitHub , or  unsubscribe .
Triage notifications on the go with GitHub Mobile for  iOS or  Android .
 
 
С уважением,
Вадим Пузанов
 

vvip-68, 2021-09-14:
> > Which issue do you have with android application in GyverPanel project?
> > When I install the script on the NodeMCU and connect the Android App to the panel, my inputs are going crazy. When I try to select an effect the list of effects is scrolling really fast.
> > Image uploads and drawing by hand is absolutely not working.

Could you somehow send me wideo with app behaviour?
I do noy understand what do you mean 'going crasy' and scrolling the list of effects.

Do you use special application GyverPlayer for draw and upload images in GyverPanel project?
Do you use special android application from GyverPanel project (not the app from GyverMatrix project)?

TimoUrban, 2021-09-14:
I promise I will send a video of the issue. But at the moment I am very happy running my matrix with the GyverMatrixWiFi Code :-)  First I want to finish my 3D printed case for the pixel matrix.

The specs of the GyverPanelWiFi are also very interesting for me. I ordered another NodeMCU  board so I can install GyverPanelWifi again.

Do you want to send me an e-mail adress or what is the best place to discuss?

Best wishes
Timo

vvip-68, 2021-09-14:
The best practice to quick communication is usage of VK dialog (messenger) here https://vk.com/iivanovii
but I guess you do not have an account in this social network.

You may true to use skype dialog to vvip68 or viber messenger or telegram messenger
Both of them require phone number to start communication, which I do not want to present public.
The same with email. So - either here or in skype or let me way to tell you phone number or email in private manner.

TimoUrban, 2021-09-14:
I added you via Skype :-)

Closed 2021-09-14.

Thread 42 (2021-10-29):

Прошу подсказать

lBoneSl, 2021-10-29:
Плата прошилась (NodeMcu Lua v3)

В конце есть сообщение:

Leaving...
Hard resetting via RTS pin...

Но похоже перезагрузка не происходит и скетч не выполняется (или плату нужно самому перезагрузить?)
В мониторинге порта только это:

21:04:52.697 -> ⸮⸮⸮l⸮⸮⸮⸮⸮⸮⸮⸮

Соответственно нужен совет, что не так инструкции уже 10 раз пересмотрел

vvip-68, 2021-10-30:
> адрес и порт использую что в скетче прописанны:
#define udp_port 2390
byte IP_STA[] = {192, 168, 0, 106};

А в логе в мониторе порта пишется, что подключение к сети выполнено и именно этот адрес получила матрица?
Может она все же точку доступа создает 192.168.4.1? При 4х-кратном нажатии на кнопку IP адрес выводится бегущей строкой на матрицу?

lBoneSl, 2021-10-30:
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

Спасибо, вроде разобрался, такой вопрос у меня матрица мобильная, а непосредственно напрямую телефон к матрице можно подключить? Или только открытый вайфай должен быть?

lBoneSl, 2021-10-30:
Спасибо, все теперь точно разобрался, как вам можно благодарность выслать?

vvip-68, 2021-10-30:
На гитхабе где брали проект (здесь вверху) - есть кнопка "Sponsor". Можно так поддержать проект.
Спасибо.

Closed 2021-10-30.

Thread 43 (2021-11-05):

Wifi

kost111233, 2021-11-05:
Добрый вечер, долго собирался прежде чем написать. Изначально все режимы зависали на 30 секунды, пробовал все, питания понижал и тд, помогло только перепрошивка платы до заводских. Сейчас все работает, но до того момента,пока не подключу матрицу к домашнему вайфаю. У меня ип 192.168.31.1 у роутра, я в скетч ввожу например 192.168.31.100, прошивается, режимы работают, но больше нет точки доступа самой платы, не возможно подключится. Пробовал и в скетче вводить и в приложение, так же менял каждый раз eeprom.

vvip-68, 2021-11-05:
Если после включения точка доступа не создается - значит устройство успешно подключилась к сети.
Принудительно создавать точку доступа даже когда она успешно подключилась к локальной сети - только если в настройках соединения в приложении установлена галка "Создавать точку доступа".
Принудительно остановить подключение к сети и создать точку доступа можно если при включении устройства в первые несколько секунд нажать н а кнопку.

Подключите устройство USB кабелем, откройте монитор порта и убедитесь, что устройство подключаясь к локальной сети получает именно тот адрес, который вы ожидаете (который вы указали в приложении при настройке подключения). Если адрес не попадает в диапазон подсетки роутера - принудительно включите точку доступа нажатием кнопки при старте устройства до того как оно успело подключиться к локальной сети.

Затем, из приложения подключитесь к точке доступа и настройте еще раз подключение к сети (имя сети, пароль, IP адрес, который должно получать устройство в сети).

По поводу "зависали на 30 секунды" - ничего сказать не могу. С таким не  сталкивался.

vvip-68, 2021-11-05:
И - проект Gyver**Matrix**WiFi - устаревший, уже не поддерживается и ошибки не правятся, даже если они есть. Рекомендуется перейти на проект GyverPanelWiFi - там все те же возможности что и в этом проекте, плюс куча дополнительных возможностей.

kost111233, 2021-11-05:
Я сначала и начал с вашего проекта, но не знал что проблема в плате, ужасно все тормозило. Ваш проект у меня работал с задержкой в минуту наверно, стоп кадр, поэтому решил этот попробовать, там задержки были меньше, сейчас все хорошо.

Значит плата не может одновременно быть подключена к домашней сети и создавать свою точку доступа? Не знал об этом.

Спасибо за помощь, буду пытаться запускать ваш проект. Единственное не понял по работе часов в описании, у меня маленькая матрица 20х10, видел видео других пользователи, они будут только как бегущая строка?

vvip-68, 2021-11-05:
Они будут шрифтом 3x5, для которых достаточно ширины в 15 колонок. Для часов шрифтом 5x7 нужна ширина в 23 колонки минимум. Часы в бегущей строке будут шрифтом 5x8.

vvip-68, 2021-11-05:
> Значит плата не может одновременно быть подключена к домашней сети и создавать свою точку доступа? Не знал об этом.

Плата МОЖЕТ быть одновременно в локальной сети и создавать точку доступа. Но для этого в настройках нужно поставить соответствующую галочку.

kost111233, 2021-11-05:
Извините за глупые вопросы. Очень крутой проект, потрачено много сил и времени на него, даже инструкция есть. Но все равно появляются такие как я:)  спасибо за помощь

vvip-68, 2021-11-05:
> Правильно понял, подключаю в сеть и чтоб зайти в приложение, нужно в первые секунды нажать на кнопку переключения режимов, тогда появится точка доступа самой платы и там уже все настраивать?

Плата подключается к локальной сети. Если подключение успешно - точка доступа не создается. Подключиться к плате можно из приложения через локальную сеть.

Если подключиться к сети не удалось - автоматически создается точка доступа. Подключиться из приложения можно и через точку доступа напрямую.

Если в настройках установить соответствующую галочку - плата будет И подключаться к локальной сети И создавать точку доступа. Подключиться можно и через сеть и через точку доступа.

vvip-68, 2021-11-05:
Нажати не кнопку в первые секунды отменяет подключение к локальной сети и создает точку доступа

Closed 2021-11-05.

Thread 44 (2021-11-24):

Не видит ленту.

Paqwa12, 2021-11-24:
Добрый вечер, недавно собрал данную сборку на NodeMcu и столкнулся с такой проблемой, плата не выводит изображение на ленту, все провода подключены в том числе и питание и на ленту и на плату, к приложению плата подключается.
Что делать?

vvip-68, 2021-11-24:
Подключить ленту именно к тому пину микроконтроллера, на который выводится управляющий сигнал, а не к случайному. Плюс проверить, что лента подключена к пину контроллера входом (DIn), а не выходом (DOut).

Closed 2021-11-24.

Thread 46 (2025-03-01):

fonts.h

qulet, 2025-03-01:
Спасибо, что поделились кодом и программным обеспечением для Android. Я собрал плату на базе Node MCU ESP8266, все функции работают в режиме точки доступа WIFI. Я ввел правильное сетевое имя и пароль в скетч, и скомпилированная программа была загружена в ESP8266. Не подключается в режиме WIFI.
На самом деле это не самая большая моя проблема. Проблема заключается в отправке текстовых сообщений с польскими буквами: ąśćńłóężź. Можно пожалуйста файл fonts.h с такими буквами? Или инструкцию как сгенерировать такой файл.

vvip-68, 2025-03-01:
Смотрите что пишет в мониторе порта в момент подключения.
Попробуйте из приложения подключиться к точке доступа, установить пароль и имя сети непосредственно в приложении.

По буквам польского алфавита - прошивка их нге поддерживает.
Для поддержки - нужно переписывать программу (скетч).
Выбранная именно вами версия GyverMatrixWiFi - настолько древняя (ей уже более 6 лет), что в ней вообще нет поддержки никаких языков кроме русского и английского (кириллица и латиница).

Частично поддержка есть в версии 1.13 (https://github.com/vvip-68/GyverPanelWiFi) и в самой последней 1.14 https://github.com/vvip-68/LedPanelWiFi/tree/main/firmware/LedPanelWiFi_v1.14, но польского там нет.

Нужно писать код (сопоставление UTF-8 кода символа),  с отрисовкой символа латиницы и соответствующего диакритического знака в соответствующей позиции.

Для версии 1.14 в ее вики есть статья как добавлять свои буквы ы знакогенератор скетча - https://github.com/vvip-68/LedPanelWiFi/wiki/Добавление-своих-символов-в-шрифт.  Часть про рисование можно пропустить - базис уже есть, нужно только добавить код отрисовки и сопоставления диакритических символов.

Если по полной программе для версии 1.14 - там нужно бы еще все текстовые поля в интерфейсе перевести на польский.

vvip-68, 2025-03-03:
Справились? Если нет - хочу предложить небольшую сделку, (около $3.20) - мне нужна помощь...
Если что - пишите на vvip@mail.ru

vvip-68, 2025-03-09:
А,вот еще вспомнил предположение - проверьте в настройках своего роутера не стоит ли галочка "Изоляция клиентов" (Client isolation) - если она включена- каждое устройство в сети пожет отсылать данные в /из интернета, но между собой общаться не могут - изолированы. Снимите эту галочку.

Closed 2025-03-02.

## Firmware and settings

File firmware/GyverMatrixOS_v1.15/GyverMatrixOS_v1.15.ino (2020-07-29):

// Скетч к проекту "Адресная матрица"
// Гайд по постройке матрицы: https://alexgyver.ru/matrix_guide/
// Страница базового проекта (схемы, описания): https://alexgyver.ru/GyverMatrixBT/
// Страница проекта на GitHub: https://github.com/vvip-68/GyverMatrixWiFi
// Автор: AlexGyver Technologies, 2018
// Дальнейшее развитие: vvip, 2019,2020
// https://AlexGyver.ru/

#define FIRMWARE_VER F("\n\nGyverMatrix-WiFi v.1.15.2020.0729")

// ************************ МАТРИЦА *************************

#define BRIGHTNESS 32         // стандартная маскимальная яркость (0-255)
uint16_t CURRENT_LIMIT=5000;  // лимит по току в миллиамперах, автоматически управляет яркостью (пожалей свой блок питания!) 0 - выключить лимит

#define DEVICE_TYPE 1         // Использование матрицы: 0 - свернута в трубу для лампы; 1 - плоская матрица в рамке   

// ******************* ПОДКЛЮЧЕНИЕ К СЕТИ *******************
                                             // Внимание!!! Если вы меняете эти значения ПОСЛЕ того, как прошивка уже хотя бы раз была загружена в плату и выполнялась,
                                             // чтобы изменения вступили в силу нужно также изменить значение константы EEPROM_OK в первой строке в файле eeprom.ino 
                                             // 
#define NETWORK_SSID ""                      // Имя WiFi сети - пропишите здесь или задайте из программы на смартфоне
#define NETWORK_PASS ""                      // Пароль для подключения к WiFi сети - пропишите здесь или задайте из программы на смартфоне
#define DEFAULT_AP_NAME "MatrixAP"           // Имя точки доступа по умолчанию 
#define DEFAULT_AP_PASS "12341234"           // Пароль точки доступа по умолчанию
#define udp_port 2390                        // Порт матрицы для подключения из программы на смартфоне
byte IP_STA[] = {192, 168, 0, 106};          // Статический адрес матрицы в локальной сети WiFi

#define DEFAULT_NTP_SERVER "ru.pool.ntp.org" // NTP сервер по умолчанию "time.nist.gov"

// ****************** ПИНЫ ПОДКЛЮЧЕНИЯ *******************

// Внимание!!! При использовании платы микроконтроллера Wemos D1 (xxxx) и выбранной в менеджере плат платы "Wemos D1 (xxxx)"
// прошивка скорее всего нормально работать не будет. 
// Наблюдались следующие сбои у разных пользователей:
// - нестабильная работа WiFi (постоянные отваливания и пропадание сети) - попробуйте варианты с разным значением параметров компиляции IwIP в Arduino IDE
// - прекращение вывода контрольной информации в Serial.print() - в монитор порта не выводится
// - настройки в EEPROM не сохраняются
// Думаю все эти проблемы из за некорректной работы ядра ESP8266 для платы (варианта компиляции) Wemos D1 (xxxx) в версии ядра ESP8266 2.5.2
// Диод на ногу питания Wemos как нарисовано в схеме от Alex Gyver не ставить (!!!), конденсатор по питанию - для NodeMCU - желателен, для Wemos - обязателен (!!!)

// пины подписаны согласно pinout платы, а не надписям на пинах!
// esp8266 - плату выбирал "Node MCU v3 (SP-12E Module)"

/*
 * NodeMCU v1.0 (ESP-12E)
 * Физическое подключение:
 * Матрица зигзаг, левый нижний угол, направление вапрво
 * Пин ленты    - D2
 * Пин кнопки   - D6
 * Фоторезистор - A0
 * MP3Player    - D3 к RX, D4 к TX плеера 
 * В менеджере плат выбрано NodeMCU v1.0 (ESP-12E)
 */ 
#if defined(ESP8266)
#define WIDTH 48              // ширина матрицы
#define HEIGHT 16             // высота матрицы
#define SEGMENTS 1            // диодов в одном "пикселе" (для создания матрицы из кусков ленты)
#define MATRIX_TYPE 0         // тип матрицы: 0 - зигзаг, 1 - параллельная
#define CONNECTION_ANGLE 0    // угол подключения: 0 - левый нижний, 1 - левый верхний, 2 - правый верхний, 3 - правый нижний
#define STRIP_DIRECTION 0     // направление ленты из угла: 0 - вправо, 1 - вверх, 2 - влево, 3 - вниз
#define USE_MP3 1             // поставьте 0, если у вас нет звуковой карты MP3 плеера
#define USE_PHOTO 1           // поставьте 0, если вы не используете фоторезистор как датчик освещенности
 
#define PHOTO_PIN 0           // пин фоторезистора
#define LED_PIN 2             // физический D2 пин ленты
#define PIN_BTN 12            // физический D6 кнопка подключена сюда (PIN --- КНОПКА --- GND)
#define SRX D4                // физический D4 is RX of ESP8266, connect to TX of DFPlayer
#define STX D3                // физический D3 is TX of ESP8266, connect to RX of DFPlayer module
#endif
/*
 * Wemos D1 mini
 * Физическое подключение:
 * Матрица зигзаг, правый нижний угол, направление вверх
 * Пин ленты    - D3
 * Пин кнопки   - D2
 * Фоторезистор - A0
 * MP3Player    - не подключен
 * В менеджере плат выбрано NodeMCU v1.0 (ESP-12E)
 */ 
/* 
#if defined(ESP8266)
#define WIDTH 16              // ширина матрицы
#define HEIGHT 16             // высота матрицы
#define SEGMENTS 1            // диодов в одном "пикселе" (для создания матрицы из кусков ленты)
#define MATRIX_TYPE 0         // тип матрицы: 0 - зигзаг, 1 - параллельная
#define CONNECTION_ANGLE 3    // угол подключения: 0 - левый нижний, 1 - левый верхний, 2 - правый верхний, 3 - правый нижний
#define STRIP_DIRECTION 1     // направление ленты из угла: 0 - вправо, 1 - вверх, 2 - влево, 3 - вниз
#define USE_MP3 0             // поставьте 0, если у вас нет звуковой карты MP3 плеера
#define USE_PHOTO 1           // поставьте 0, если вы не используете фоторезистор как датчик освещенности

#define PHOTO_PIN 0           // пин фоторезистора
#define LED_PIN 3             // пин ленты
#define PIN_BTN 4             // кнопка подключена сюда (PIN --- КНОПКА --- GND)
#define SRX D4                // не используется, но требуется для компиляции скетча
#define STX D3                // не используется, но требуется для компиляции скетча
#endif
*/

/*
 * NodeMCU ESP32
 * Физическое подключение:
 * Матрица зигзаг, левый нижний угол, направление вапрво
 * Пин ленты    - 2
 * Пин кнопки   - 4
 * MP3Player    - 17 к RX, 16 к TX плеера 
 * TM1637       - 23 к DIO, 22 к CLK
 * В менеджере плат выбрано "ESP32 Dev Module"
 */ 
#if defined(ESP32)
#define WIDTH 16              // ширина матрицы
#define HEIGHT 16             // высота матрицы
#define SEGMENTS 1            // диодов в одном "пикселе" (для создания матрицы из кусков ленты)
#define MATRIX_TYPE 0         // тип матрицы: 0 - зигзаг, 1 - параллельная
#define CONNECTION_ANGLE 0    // угол подключения: 0 - левый нижний, 1 - левый верхний, 2 - правый верхний, 3 - правый нижний
#define STRIP_DIRECTION 0     // направление ленты из угла: 0 - вправо, 1 - вверх, 2 - влево, 3 - вниз
#define USE_MP3 1             // поставьте 0, если у вас нет звуковой карты MP3 плеера

#define LED_PIN (2U)          // пин ленты, физически подключена к пину D2 на плате
#define PIN_BTN (4U)          // кнопка подключена сюда (PIN --- КНОПКА --- GND)
#define SRX (16U)             // 16 is RX of ESP32, connect to TX of DFPlayer
#define STX (17U)             // 17 is TX of ESP32, connect to RX of DFPlayer module
#endif

// Подключение используемых библиотек
#if defined(ESP8266)
  #include <ESP8266WiFi.h>
#endif

// Подключение используемых библиотек
#include <WiFiUdp.h>
#include <TimeLib.h>
#include <EEPROM.h>
#include "FastLED.h"
#include "timerMinim.h"
#include "GyverButton.h"
#include "GyverFilters.h"

#if (USE_MP3 == 1)
#include "DFRobotDFPlayerMini.h"      // Установите в менеджере библиотек стандартную библиотеку DFRobotDFPlayerMini ("DFPlayer - A Mini MP3 Player For Arduino" )
#include <SoftwareSerial.h>          // Установите в менеджере библиотек "EspSoftwareSerial" для ESP8266/ESP32 https://github.com/plerup/espsoftwareserial/
#endif

#include "fonts.h"
#include "bitmap1.h"
//#include "bitmap2.h"
//#include "bitmap3.h"
//#include "bitmap4.h"
//#include "bitmap5.h"

#if defined(ESP32)
  #include <WiFi.h>
#ifndef min
  #define min(a,b) (((a) < (b)) ? (a) : (b))
#endif
#ifndef max
  #define max(a,b) (((a) > (b)) ? (a) : (b))
#endif
#endif

#define COLOR_ORDER GRB       // порядок цветов на ленте. Если цвет отображается некорректно - меняйте. Начать можно с RGB

// ******************** ЭФФЕКТЫ И РЕЖИМЫ ********************

// Список и порядок эффектов и игр, передаваймый в приложение на смартфоне. Данные списки попадают в комбобокс выбора,
// чей индекс передается из приложения в контроллер матрицы для выбора, поэтому порядок должен соответствовать
// спискам эффектов и игр, определенному ниже в DEMO_XXXXXX
#define EFFECT_LIST F("Снегопад,Шарик,Радуга,Пейнтбол,Огонь,The Matrix,Шарики,Часы,Звездопад,Конфетти,Радуга диагональная,Цветной шум,Облака,Лава,Плазма,Радужные переливы,Полосатые переливы,Зебра,Шумящий лес,Морской прибой,Светлячки,Водоворот,Лампа,Рассвет,Анимация") /* 1,Анимация 2,Анимация 3,Анимация 4,Анимация 5*/
#define ALARM_LIST  F("Снегопад,Шарик,Радуга,Пейнтбол,Огонь,The Matrix,Шарики,Звездопад,Конфетти,Радуга диагональная,Цветной шум,Облака,Лава,Плазма,Радужные переливы,Полосатые переливы,Зебра,Шумящий лес,Морской прибой,Светлячки,Водоворот,Рассвет,Анимация") /* 1,Анимация 2,Анимация 3,Анимация 4,Анимация 5*/
#define GAME_LIST   F("Змейка,Тетрис,Лабиринт,Runner,Арканоид")

#if (USE_MP3 == 1)
// SD карточка в MP3 плеере (DFPlayer) содержить в корне две папки - "1" и "2"
// Папка "1" содержит MP3 файлы звуков, проигрываемых при наступлении события будильника
// Папка "2" содержит MP3 файлы звуков, проигрываемых при наступлении события рассвета
// DFPlayer не имеет возможности считывать имена файлов, только возможность получить количество файлов в папке.
// Команда на воспроизведение звука означает - играть файл с индексом (номером) N из папки M
// Номера файлов определяются таблицей размещения файлов SD-карты (FAT)  и формируются в порядке очереди записи файлов на чистую флэшку
// Так, файл записанный в папку первым получает номер 1, вторыи - 2 и так далее и ника не зависит от имен файлов
// Данные массивы содержат отображаемые в приложении имена звуков в порядке, соответствующем нумерации записанных в папки файлов.
#define ALARM_SOUND_LIST F("One Step Over,In the Death Car")            // Список звука для комбобокса "Звук будильника" в приложении на смартфоне
#define DAWN_SOUND_LIST F("Птицы,Гроза,Прибой,Дождь,Ручей,Мантра")      // Список звука для комбобокса "Звук рассвета" в приложении на смартфоне
#endif

#define D_TEXT_SPEED 100      // скорость бегущего текста по умолчанию (мс)
#define D_TEXT_SPEED_MIN 10
#define D_TEXT_SPEED_MAX 255

#define D_EFFECT_SPEED 80     // скорость эффектов по умолчанию (мс)
#define D_EFFECT_SPEED_MIN 0
#define D_EFFECT_SPEED_MAX 255

#define D_GAME_SPEED 250      // скорость игр по умолчанию (мс)
#define D_GAME_SPEED_MIN 25
#define D_GAME_SPEED_MAX 375

#define D_GIF_SPEED 100       // скорость гифок (мс)
#define DEMO_GAME_SPEED 60    // скорость игр в демо режиме (мс)

boolean AUTOPLAY = 1;         // 0 выкл / 1 вкл автоматическую смену режимов (откл. можно со смартфона)
#define AUTOPLAY_PERIOD 30    // время между авто сменой режимов (секунды)
#define IDLE_TIME 10          // время бездействия кнопок или Bluetooth (в минутах) после которого запускается автосмена режимов и демо в играх

// о поддерживаемых цветах читай тут https://alexgyver.ru/gyvermatrixos-guide/
#define GLOBAL_COLOR_1 CRGB::Green    // основной цвет №1 для игр
#define GLOBAL_COLOR_2 CRGB::Orange   // основной цвет №2 для игр

#define SCORE_SIZE 0          // размер символов счёта в игре. 0 - маленький для 8х8 (шрифт 3х5), 1 - большой (шрифт 5х7)
#define FONT_TYPE 1           // (0 / 1) два вида маленького шрифта в выводе игрового счёта
#define SMOOTH_CHANGE 0     // плавная смена режимов через чёрный

// ************** ОТКЛЮЧЕНИЕ КОМПОНЕНТОВ СИСТЕМЫ (для экономии памяти) *************

// внимание! отключение модуля НЕ УБИРАЕТ его эффекты из списка воспроизведения!
// Это нужно сделать вручную во вкладке custom, удалив ненужные функции

#define USE_NOISE_EFFECTS 1 // крутые полноэкранные эффекты (0 нет, 1 да) СИЛЬНО ЖРУТ ПАМЯТЬ!!!
#define OVERLAY_CLOCK 1     // часы на фоне всех эффектов и игр. Жрёт SRAM память!

// включение / отключение игр
#define USE_SNAKE 1         // игра змейка (0 нет, 1 да)
#define USE_TETRIS 1        // игра тетрис (0 нет, 1 да)
#define USE_MAZE 1          // игра лабиринт (0 нет, 1 да)
#define USE_RUNNER 1        // игра бегалка-прыгалка (0 нет, 1 да)
#define USE_ARKAN 1         // игра арканоид

// ******************************** ДЛЯ РАЗРАБОТЧИКОВ ********************************

#define DEBUG 0
#define NUM_LEDS WIDTH * HEIGHT * SEGMENTS

CRGB leds[NUM_LEDS];

// Ориентация отображения часов
byte CLOCK_ORIENT = 0;     // 0 горизонтальные, 1 вертикальные

// Макрос центрирования отображения часов на матрице
#define CLOCK_X_H (byte((WIDTH - (4*3 + 3*1)) / 2.0 + 0.51))  // 4 цифры * (шрифт 3 пикс шириной) 3 + пробела между цифрами), /2 - в центр 
#define CLOCK_Y_H (byte((HEIGHT - (1*5)) / 2.0 + 0.51))       // Одна строка цифр 5 пикс высотой  / 2 - в центр
#define CLOCK_X_V (byte((WIDTH - (2*3 + 1)) / 2.0 + 0.51))    // 2 цифры * (шрифт 3 пикс шириной) 1 + пробел между цифрами) /2 - в центр
#define CLOCK_Y_V (byte((HEIGHT - (2*5 + 1)) / 2.0 + 0.51))   // Две строки цифр 5 пикс высотой + 1 пробел между строкми / 2 - в центр

// Макрос центрирования отображения календаря на матрице
#define CAL_X (byte((WIDTH - (4*3 + 1)) / 2.0))               // 4 цифры * (шрифт 3 пикс шириной) 1 + пробел между цифрами) /2 - в центр
#define CAL_Y (byte((HEIGHT - (2*5 + 1)) / 2.0))              // Две строки цифр 5 пикс высотой + 1 пробел между строкми / 2 - в центр

// Позиции отображения часов и календаря
byte CALENDAR_X = CAL_X;
byte CALENDAR_Y = CAL_Y;
byte CLOCK_X = CLOCK_X_H;     // Для вертикальных часов CLOCK_X_V и CLOCK_Y_V
byte CLOCK_Y = CLOCK_Y_H;

// Часы могут отображаться: 
// - вертикальные при высоте матрицы >= 11 и ширине >= 7; 
// - горизонтальные при ширене матрицы >= 15 и высоте >= 5
bool allowVertical = WIDTH >= 7 && HEIGHT >= 11;
bool allowHorizontal = WIDTH >= 15 && HEIGHT >= 7;

// Режим цвета часов
byte COLOR_MODE = 0;
//                               0 - монохромные цвета, определенные для режимов NORMAL_CLOCK_COLOR, CONTRAST_COLOR_1, CONTRAST_COLOR_2, CONTRAST_COLOR_3 в clock.ino
//                               1 - радужная смена (каждая цифра)
//                               2 - радужная смена (часы, точки, минуты)
//                               3 - заданные цвета (часы, точки, минуты) - HOUR_COLOR, DOT_COLOR, MIN_COLOR в clock.ino

bool useRandomSequence = true;   // Использовать случайный порядок следования эффектов

// Порядок следования эффектов и игр в демо-режиме (см. customModes() в custom.ino) ID с 0 до MODES_AMOUNT-1
// Если требуется изменить порядок следования эффектов в демо-режиме - (а также добавить/удалить режимы) - редактируйте
// последовательность тут. Наличие - тут и в customModes() в custom.ino
#define DEMO_TEXT_0              0
#define DEMO_TEXT_1              1
#define DEMO_TEXT_2              2
#define DEMO_NOISE_MADNESS       3
#define DEMO_NOISE_CLOUD         4
#define DEMO_NOISE_LAVA          5
#define DEMO_NOISE_PLASMA        6
#define DEMO_NOISE_RAINBOW       7
#define DEMO_NOISE_RAINBOW_STRIP 8
#define DEMO_NOISE_ZEBRA         9
#define DEMO_NOISE_FOREST       10
#define DEMO_NOISE_OCEAN        11
#define DEMO_SNOW               12
#define DEMO_SPARKLES           13
#define DEMO_MATRIX             14
#define DEMO_STARFALL           15
#define DEMO_BALL               16
#define DEMO_BALLS              17
#define DEMO_RAINBOW            18
#define DEMO_RAINBOW_DIAG       19
#define DEMO_FIRE               20
#define DEMO_LIGHTERS           21
#define DEMO_PAINTBALL          22
#define DEMO_SWIRL              23
#define DEMO_SNAKE              24
#define DEMO_TETRIS             25
#define DEMO_MAZE               26
#define DEMO_RUNNER             27
#define DEMO_ARKANOID           28
#define DEMO_CLOCK              29
#define DEMO_FILL_COLOR         30  // Заливка матрицы одним цветом
#define DEMO_DAWN_ALARM         31  // Режим эффекта будильника "Рассвет"
// ---------------------------------
#define DEMO_ANIMATION_1        32
//#define DEMO_ANIMATION_2        33
//#define DEMO_ANIMATION_3        34
//#define DEMO_ANIMATION_4        35
//#define DEMO_ANIMATION_5        36

// не забудьте указать количество режимов для корректного переключения с последнего на первый
// количество кастомных режимов (которые переключаются сами или кнопкой)
#define MODES_AMOUNT 33 // 37

// ---------------------------------
#define DEMO_DAWN_ALARM_SPIRAL 253  // Специальный режим, вызывается из DEMO_DAWN_ALARM для ламп на круговой матрице - огонек по спирали
#define DEMO_DAWN_ALARM_SQUARE 254  // Специальный режим, вызывается из DEMO_DAWN_ALARM для плоских матриц - огонек по спирали на плоскости матрицы
// ---------------------------------

// Сквозная нумерация (ID) эффектов в группе эффектов
#define EFFECT_SNOW                 0
#define EFFECT_BALL                 1
#define EFFECT_RAINBOW              2
#define EFFECT_PAINTBALL            3
#define EFFECT_FIRE                 4
#define EFFECT_MATRIX               5
#define EFFECT_BALLS                6
#define EFFECT_CLOCK                7
#define EFFECT_STARFALL             8
#define EFFECT_SPARKLES             9
#define EFFECT_RAINBOW_DIAG        10
#define EFFECT_NOISE_MADNESS       11
#define EFFECT_NOISE_CLOUD         12
#define EFFECT_NOISE_LAVA          13
#define EFFECT_NOISE_PLASMA        14
#define EFFECT_NOISE_RAINBOW       15
#define EFFECT_NOISE_RAINBOW_STRIP 16
#define EFFECT_NOISE_ZEBRA         17
#define EFFECT_NOISE_FOREST        18
#define EFFECT_NOISE_OCEAN         19
#define EFFECT_LIGHTERS            20
#define EFFECT_SWIRL               21
#define EFFECT_FILL_COLOR          22
#define EFFECT_DAWN_ALARM          23
#define EFFECT_ANIMATION_1         24
//#define EFFECT_ANIMATION_2         25
//#define EFFECT_ANIMATION_3         26
//#define EFFECT_ANIMATION_4         27
//#define EFFECT_ANIMATION_5         28

#define MAX_EFFECT                 25 // 29 // количество эффектов, определенных в прошивке
#define MAX_SPEC_EFFECT            10       // количество эффектов быстрого доступа -> 0..9

// Сквозная нумерация (ID) игр в группе игр
#define GAME_SNAKE               0
#define GAME_TETRIS              1
#define GAME_MAZE                2
#define GAME_RUNNER              3
#define GAME_ARKANOID            4

#define MAX_GAME                 5         // количество игр, определенных в прошивке
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
void loop() {
  bluetoothRoutine();
}

// -----------------------------------------

void startWiFi() {

  WiFi.disconnect(true);
  wifi_connected = false;
  WiFi.mode(WIFI_STA);

  // Пытаемся соединиться с роутером в сети
  if (strlen(ssid) > 0) {
    Serial.print(F("\nПодключение к "));
    Serial.print(ssid);

    if (IP_STA[0] + IP_STA[1] + IP_STA[2] + IP_STA[3] > 0) {
      WiFi.config(IPAddress(IP_STA[0], IP_STA[1], IP_STA[2], IP_STA[3]),  // 192.168.0.106
                  IPAddress(IP_STA[0], IP_STA[1], IP_STA[2], 1),          // 192.168.0.1
                  IPAddress(255, 255, 255, 0),                            // Mask
                  IPAddress(IP_STA[0], IP_STA[1], IP_STA[2], 1),          // DNS1 192.168.0.1
                  IPAddress(8, 8, 8, 8));                                 // DNS2 8.8.8.8                  
    }
    WiFi.begin(ssid, pass);

    // Проверка соединения (таймаут 10 секунд)
    for (int j = 0; j < 10; j++ ) {
      wifi_connected = WiFi.status() == WL_CONNECTED;
      if (wifi_connected) {
        // Подключение установлено
        Serial.println();
        Serial.print(F("WiFi подключен. IP адрес: "));
        Serial.println(WiFi.localIP());
        break;
      }
      delay(500);
      Serial.print(".");
    }
    Serial.println();

    if (!wifi_connected)
      Serial.println(F("Не удалось подключиться к сети WiFi."));
  }
}

void startSoftAP() {
  WiFi.softAPdisconnect(true);
  ap_connected = false;

  Serial.print(F("Создание точки доступа "));
  Serial.print(apName);

  ap_connected = WiFi.softAP(apName, apPass);

  for (int j = 0; j < 10; j++ ) {
    if (ap_connected) {
      Serial.println();
      Serial.print(F("Точка доступа создана. Сеть: '"));
      Serial.print(apName);
      // Если пароль совпадает с паролем по умолчанию - печатать для информации,
      // если был изменен пользователем - не печатать
      if (strcmp(apPass, "12341234") == 0) {
        Serial.print(F("'. Пароль: '"));
        Serial.print(apPass);
      }
      Serial.println(F("'."));
      Serial.print(F("IP адрес: "));
      Serial.println(WiFi.softAPIP());
      break;
    }

    WiFi.enableAP(false);
    WiFi.softAPdisconnect(true);
    delay(500);

    Serial.print(".");
    ap_connected = WiFi.softAP(apName, apPass);
  }
  Serial.println();

  if (!ap_connected)
    Serial.println(F("Не удалось создать WiFi точку доступа."));
}

void printNtpServerName() {
  Serial.print(F("NTP-сервер "));
  Serial.print(ntpServerName);
  Serial.print(F(" -> "));
  Serial.println(timeServerIP);
}

void connectToNetwork() {
  // Подключиться к WiFi сети
  startWiFi();

  // Если режим точки тоступане используется и к WiFi сети подключиться не удалось - создать точку доступа
  if (!wifi_connected) {
    WiFi.mode(WIFI_AP);
    startSoftAP();
  }

  if (useSoftAP && !ap_connected) startSoftAP();

  // Сообщить UDP порт, на который ожидаются подключения
  if (wifi_connected || ap_connected) {
    Serial.print(F("UDP-сервер на порту "));
    Serial.println(udp_port);
  }
}

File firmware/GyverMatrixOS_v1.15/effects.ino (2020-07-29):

// эффекты

// **************** НАСТРОЙКИ ЭФФЕКТОВ ****************
// эффект "шарики"
#define BALLS_AMOUNT 3    // количество "шариков"
#define CLEAR_PATH 1      // очищать путь
#define BALL_TRACK 1      // (0 / 1) - вкл/выкл следы шариков
#define TRACK_STEP 70     // длина хвоста шарика (чем больше цифра, тем хвост короче)

// эффект "квадратик"
#define BALL_SIZE 3       // размер квадрата
#define RANDOM_COLOR 1    // случайный цвет при отскоке

// эффект "огонь"
#define SPARKLES 1        // вылетающие угольки вкл выкл
#define HUE_ADD 0         // добавка цвета в огонь (от 0 до 230) - меняет весь цвет пламени

// эффект "кометы"
#define TAIL_STEP 100     // длина хвоста кометы
#define SATURATION 150    // насыщенность кометы (от 0 до 255)
#define STAR_DENSE 60     // количество (шанс появления) комет

// эффект "конфетти"
#define DENSE 3           // плотность конфетти
#define BRIGHT_STEP 70    // шаг уменьшения яркости

// эффект "снег"
#define SNOW_DENSE 10     // плотность снегопада

// эффект "Светляки"
#define LIGHTERS_AM 35    // количество светляков

// --------------------- ДЛЯ РАЗРАБОТЧИКОВ ----------------------

byte hue;

// *********** снегопад 2.0 ***********
void snowRoutine() {
  if (loadingFlag) {
    modeCode = MC_SNOW;
    loadingFlag = false;
    FastLED.clear();  // очистить
  }

  // сдвигаем всё вниз
  for (byte x = 0; x < WIDTH; x++) {
    for (byte y = 0; y < HEIGHT - 1; y++) {
      drawPixelXY(x, y, getPixColorXY(x, y + 1));
    }
  }

  for (byte x = 0; x < WIDTH; x++) {
    // заполняем случайно верхнюю строку
    // а также не даём двум блокам по вертикали вместе быть
    if (getPixColorXY(x, HEIGHT - 2) == 0 && (random(0, SNOW_DENSE) == 0))
      drawPixelXY(x, HEIGHT - 1, 0xE0FFFF - 0x101010 * random(0, 4));
    else
      drawPixelXY(x, HEIGHT - 1, 0x000000);
  }
}

// ***************************** БЛУДНЫЙ КУБИК *****************************
int coordB[2];
int8_t vectorB[2];
CRGB ballColor;

void ballRoutine() {
  if (loadingFlag) {
    for (byte i = 0; i < 2; i++) {
      coordB[i] = WIDTH / 2 * 10;
      vectorB[i] = random(8, 20);
      ballColor = CHSV(random(0, 9) * 28, 255, 255);
    }
    modeCode = MC_BALL;
    loadingFlag = false;
  }
  for (byte i = 0; i < 2; i++) {
    coordB[i] += vectorB[i];
    if (coordB[i] < 0) {
      coordB[i] = 0;
      vectorB[i] = -vectorB[i];
      if (RANDOM_COLOR) ballColor = CHSV(random(0, 9) * 28, 255, 255);
      //vectorB[i] += random(0, 6) - 3;
    }
  }
  if (coordB[0] > (WIDTH - BALL_SIZE) * 10) {
    coordB[0] = (WIDTH - BALL_SIZE) * 10;
    vectorB[0] = -vectorB[0];
    if (RANDOM_COLOR) ballColor = CHSV(random(0, 9) * 28, 255, 255);
    //vectorB[0] += random(0, 6) - 3;
  }
  if (coordB[1] > (HEIGHT - BALL_SIZE) * 10) {
    coordB[1] = (HEIGHT - BALL_SIZE) * 10;
    vectorB[1] = -vectorB[1];
    if (RANDOM_COLOR) ballColor = CHSV(random(0, 9) * 28, 255, 255);
    //vectorB[1] += random(0, 6) - 3;
  }
  FastLED.clear();
  for (byte i = 0; i < BALL_SIZE; i++)
    for (byte j = 0; j < BALL_SIZE; j++)
      leds[getPixelNumber(coordB[0] / 10 + i, coordB[1] / 10 + j)] = ballColor;
}

// *********** радуга заливка ***********
void rainbowRoutine() {
  if (loadingFlag) {
    modeCode = MC_RAINBOW;
    loadingFlag = false;
    FastLED.clear();  // очистить
  }
  hue += 3;
  for (byte i = 0; i < WIDTH; i++) {
    CRGB thisColor = CHSV((byte)(hue + i * float(255 / WIDTH)), 255, 255);
    for (byte j = 0; j < HEIGHT; j++)      
      drawPixelXY(i, j, thisColor);   //leds[getPixelNumber(i, j)] = thisColor;
  }
}

// *********** радуга дигональная ***********
void rainbowDiagonalRoutine() {
  if (loadingFlag) {
    modeCode = MC_RAINBOW_DIAG;
    loadingFlag = false;
    FastLED.clear();  // очистить
  }
  hue += 3;
  for (byte x = 0; x < WIDTH; x++) {
    for (byte y = 0; y < HEIGHT; y++) {
      CRGB thisColor = CHSV((byte)(hue + (float)(WIDTH / HEIGHT * x + y) * (float)(255 / max(WIDTH, HEIGHT))), 255, 255);      
      drawPixelXY(x, y, thisColor); //leds[getPixelNumber(i, j)] = thisColor;
    }
  }
}

// ********************** огонь **********************
unsigned char matrixValue[8][16];
unsigned char line[WIDTH];
int pcnt = 0;

//these values are substracetd from the generated values to give a shape to the animation
const unsigned char valueMask[8][16] PROGMEM = {
  {32 , 0  , 0  , 0  , 0  , 0  , 0  , 32 , 32 , 0  , 0  , 0  , 0  , 0  , 0  , 32 },
  {64 , 0  , 0  , 0  , 0  , 0  , 0  , 64 , 64 , 0  , 0  , 0  , 0  , 0  , 0  , 64 },
  {96 , 32 , 0  , 0  , 0  , 0  , 32 , 96 , 96 , 32 , 0  , 0  , 0  , 0  , 32 , 96 },
  {128, 64 , 32 , 0  , 0  , 32 , 64 , 128, 128, 64 , 32 , 0  , 0  , 32 , 64 , 128},
  {160, 96 , 64 , 32 , 32 , 64 , 96 , 160, 160, 96 , 64 , 32 , 32 , 64 , 96 , 160},
  {192, 128, 96 , 64 , 64 , 96 , 128, 192, 192, 128, 96 , 64 , 64 , 96 , 128, 192},
  {255, 160, 128, 96 , 96 , 128, 160, 255, 255, 160, 128, 96 , 96 , 128, 160, 255},
  {255, 192, 160, 128, 128, 160, 192, 255, 255, 192, 160, 128, 128, 160, 192, 255}
};

//these are the hues for the fire,
//should be between 0 (red) to about 25 (yellow)
const unsigned char hueMask[8][16] PROGMEM = {
  {1 , 11, 19, 25, 25, 22, 11, 1 , 1 , 11, 19, 25, 25, 22, 11, 1 },
  {1 , 8 , 13, 19, 25, 19, 8 , 1 , 1 , 8 , 13, 19, 25, 19, 8 , 1 },
  {1 , 8 , 13, 16, 19, 16, 8 , 1 , 1 , 8 , 13, 16, 19, 16, 8 , 1 },
  {1 , 5 , 11, 13, 13, 13, 5 , 1 , 1 , 5 , 11, 13, 13, 13, 5 , 1 },
  {1 , 5 , 11, 11, 11, 11, 5 , 1 , 1 , 5 , 11, 11, 11, 11, 5 , 1 },
  {0 , 1 , 5 , 8 , 8 , 5 , 1 , 0 , 0 , 1 , 5 , 8 , 8 , 5 , 1 , 0 },
  {0 , 0 , 1 , 5 , 5 , 1 , 0 , 0 , 0 , 0 , 1 , 5 , 5 , 1 , 0 , 0 },
  {0 , 0 , 0 , 1 , 1 , 0 , 0 , 0 , 0 , 0 , 0 , 1 , 1 , 0 , 0 , 0 }
};

void fireRoutine() {
  if (loadingFlag) {
    modeCode = MC_FIRE;
    loadingFlag = false;
    FastLED.clear();
    generateLine();
    memset(matrixValue, 0, sizeof(matrixValue));
  }
  if (pcnt >= 100) {
    shiftUp();
    generateLine();
    pcnt = 0;
  }
  drawFrame(pcnt);
  pcnt += 30;
}


// Randomly generate the next line (matrix row)

void generateLine() {
  for (uint8_t x = 0; x < WIDTH; x++) {
    line[x] = random(64, 255);
  }
}

//shift all values in the matrix up one row

void shiftUp() {
  for (uint8_t y = HEIGHT - 1; y > 0; y--) {
    for (uint8_t x = 0; x < WIDTH; x++) {
      uint8_t newX = x;
      if (x > 15) newX = x%16;
      if (y > 7) continue;
      matrixValue[y][newX] = matrixValue[y - 1][newX];
    }
  }

  for (uint8_t x = 0; x < WIDTH; x++) {
    uint8_t newX = x;
    if (x > 15) newX = x%16;
    matrixValue[0][newX] = line[newX];
  }
}

// draw a frame, interpolating between 2 "key frames"
// @param pcnt percentage of interpolation
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

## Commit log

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2019-02-19 Константы ID эффектов и игр заменены на #define Исправлено управление играми кнопками на смартфоне Исправлено восстановление демо-режима игр после ручного возвращение в авторежим Исправлено ограничен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
    [bluetooth.ino, custom.ino, g_maze.ino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]
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2019-02-21 "Использовать в демо-режиме" для эффектов - эффекты "Дыхание", "Wdtnf", "Радуга пикс." - настройка недоступна
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2019-02-22 Вместе с часами показывать дату. Пока для режима часов без наложения на эффекты и не тестировано.
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2019-03-01 Эффект для часов рассвет (вариант для ламп со свернутой в трубу матрицей) Другие небольшие переделки и исправление ошибок
    [bluetooth.ino, clock.ino, custom.ino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]
2019-03-01 Исправлено: после паузы эффект сбрасывался на начало
    [bluetooth.ino]
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2019-03-06 В приложении для смартфона исправлена проверка наличия соединения с контроллером матрицы
2019-03-06 Добавлены режимы "Выключено" (черный экран), "Лампа" (белый экран), "Лампа с часами" (белый экран с часами), "Ночные часы" (черный экран, часы с мин. яркостью); В приложении - кнопки быстрого включен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
2019-03-28 Исправления в будильнике
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2019-04-02 Оверлей часов не отображается, пока время не инициализировано Настройки имени сети и пароль читаются из EEPROM Если не удается подключиться к сети - создается точка доступа
2019-04-02 Исправлена ошибка сработавшего будильника
    [clock.ino]
2019-04-04 Настройки сети (SSID и pass) задаются в приложении и хранятся в EEPROM Если настройки сети еще не заданы или не удалось подключиться - создается точка доступа Настройка сервера NTP с которым синхрони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
2019-04-04 Исправлена ошибка пересоздания (вкл/откл или задание нового имени) точки доступа.
    [bluetooth.ino, clock.ino, eeprom.ino]
2019-04-05 Сообщения ограничения длины полей ввода на вкладке "Подключения" Пока нет соединения видны только поля ввода адреса
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2019-04-06 Продолжаем прикручивать звук будильника - промежуточный commit 1. Инициализация платы сервера 2. Прием и обработка команд и настроек звука (не завершено)
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2019-04-08 Настройка звука будильника/рассвета через приложение. Пока параметры не применяются в будильнике - только настройка
2019-04-09 Программа - кнопка "Установить время" доступна вне зависимости от "ИспользоватьNTP" Исправлено: изменение япкости сбрасывало включенный режим.
    [bluetooth.ino]
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2019-04-11 Уменьшено время затухания звука при выключении с 5 до 2.5 сек Добавлены файлы для фрезерного станка CNC-3018 - модель решетки и управляющая программа
    [решетка.dxf]
2019-04-12 Исправлена временами некорректная работа будильника.
    [bluetooth.ino, clock.ino, custom.ino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]
2019-04-13 Исправлено для компиляции пол Arduino IDE 1.8.9
2019-04-13 Иногда будильник самопроизвольно срабатывает в 0:00. Попытка исправить.
    [clock.ino]
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2019-04-14 Файлы гравировки на корпус / рамку матрицы
    [WiFi Matrix.dxf]
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2019-04-15 Исправлена обработка кнопки при сработавшем будильнике
    [bluetooth.ino]
2019-04-17 Исправлено - если часам не удавалось синх. с NTP - отображение времени вообще пропадало.
    [bluetooth.ino, clock.ino, custom.ino]
2019-04-18 Поддержка автоматической регулировки яркости (при наличии фоторезистора в схеме) Добавлены / обновлены библиотеки
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2019-04-19 Добавлено отображение текщего IP подключения WiFi, чтобы если подключились через точку доступа и сменили настройки сети, было видно какой IP получила матрица через DHCP. Отображение текущего IP WiFi 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
2019-04-20 Реакция на 4х нажатие кнопки, если нет подключения к WiFi - пишет что нет подключения. Ранее в этом случае нажатие игнорировалось
2019-04-24 Файлы гравировки / выпиливания отверстий для МОЕЙ реализации рамки (корпуса) Небольшие изменения в скриптах
    [Front panel.dxf, Rear panel.dxf]
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2019-05-13 Задание имени WiFi сети и пароля непосредственно в скрипте
    [Front panel.dxf, Rear panel.dxf, WiFi Matrix.dxf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]
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2019-05-17 Исправлена ошибка: при пустом значении текста бегущей строки отображается текущее время и дата. Раньше - не отображалось, был черный экран.
    [bluetooth.ino]
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2019-05-19 Код матрицы: обработка времени включения/выключения матрицы (управления со смартфона еще нет) Исправлена ошибка - картинка со смартфона на матрицу передавалась в перевернутом виде
    [bluetooth.ino, clock.ino, eeprom.ino]
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2019-05-20 Исправлено: передача параметров Авторежимов 1 и 2 от матрицы в приложение на смартфоне
    [bluetooth.ino]
2019-05-20 Реализовано включение режимов по времени, в т.ч поддержка в приложении на смартфоне
    [решетка.dxf]
2019-05-21 Исправлена ошибка - если Режим 2 установлен - "Камин с часами" - он не срабатывал. Исправление - если в момент включения режимов по времени активен будильник - режимы не включаются.
    [clock.ino]
2019-05-22 При уменьшении яркости до 1 (например при автояркости) остаются слабо гореть только красные светодиоды, что приводит к совсем некорректному внешнему виду эффектов. Пожтому при данном уровне яркости а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
2019-05-24 Исправлено: при снижении яркости до минимума после автовключения ночных часов, если менялся эффект (режим), при воосстановлении яркости возобновлялся предыдущий режим без оверлея часов.
    [bluetooth.ino, custom.ino]
2019-05-24 Мелкие исправления
2019-05-24 Исправлено: ошибка установки времени включения авторежима 1 / 2 из приложения
2019-05-29 1. После отключения будильника (авто или вручную) вместо режима простых часов включается деморежим с автосменой, случайный из списка будильника) 2. Тройное нажатие кнопки включает случайный режим с а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
2019-06-05 Устранено падение программы если высота матрицы меньше высоты шрифта в эффекте бегущая строка
2019-06-08 Исправлено: Иногда при действующем эффекте, отключенном по датчику освещения до "ночных часов" при срабатывании будильника вместо рассвета - черный экран.
    [bluetooth.ino]
2019-06-09 Исправлена иногда возниающая ситуация бесконечного разбора пакета NTP ghb синхронизации часов по интернету
    [bluetooth.ino]
2019-06-18 При срабатывании будильника запоминается текущее состояние (режим) матрицы. По окончанию будильника этот режим восстанавливается. Т.е, например, если матрица была "выключена" (матрица не светится) - 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
2019-06-20 Сохранение настроек в EEPROM через 30 сек после изменения последнего сохраняемого параметра.
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2019-07-02 Исправление различных ошибок
2019-07-03 Исправлена ошибка оверлея часов при переключении некоторых режимов Исправлена ошибка включения эффекта 'Часы' в авторежиме, хотя он был отключен для показа в демо режиме
    [bluetooth.ino, clock.ino, custom.ino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]
2019-07-04 Изменен способ передачи параметров будильника из приложения в матрицу. Теперь параметры отправляются одним пакетом. Ранее пакет разбивался на несколько, что могло приводить к потере устанавливаемых п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
2019-07-04 Удалена функция проверки MP3 DFPlayer пина BUSY ввиду ненадежности определения и заметных тормозов на чтение
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2019-07-05 Исправлен расчет времени начала рассвета, если время будильника на текущий день уже в прошлом
    [clock.ino]
2019-07-05 Настройка и опрос WatchdogTimer (WDT), отладочный вывод объема свободной памяти в монитор порта
2019-07-05 Определение IP адреса сервера времени вынесено из процедуры запроса точного времени в setup() и на событие установки нового имени сервера NTP
2019-07-06 Принудительное (контрольное) отключение звука будильника после останова. MP3 DFPlayer не всегда реагирует на команду stop() и продолжает воспроизводить звук. После того как заук будильника остановлен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
2019-07-09 Проверка позиции вывода часов / календаря в зависимости от ширины / высоты матрицы
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2019-07-10 Проверка устанавливаемого IP адреса на принадлежность к локальной сети (10.x.x.x или 172.16.x.x .. 172.31.x.x или 192.168.x.x) Если адрес не принадлежит локальной сети - статический адрес сбрасываетс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
2019-07-10 Исправлено: условие проверки необходимости отключения звука, если не рассвет, не будильник и не проигрывание примеров
    [dfplayer.ino]
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2019-07-28 Сохранение/восстановление спец/режима при запуске после сбоя Сохранение / восстановление текущего выбранного цвета рисования / эффектов
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2019-07-28 Исправлен расчет времени рассвета при некоторых условиях
    [clock.ino]
2019-07-29 Настройки времени будильников сохраняются сразу в отличие от других, которые сохраняются через 30 сек после последнего изменения.
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2019-08-12 Исправлена ошибка передачи списков на смартфон
    [bluetooth.ino]
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2019-08-14 Исправлено: авторежим - включение случайного эффекта не включало автосмену режимов.
    [clock.ino, custom.ino]
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2019-08-24 Исправлена опечатка
2019-08-25 Исправлено: поле перезагрузки включается автосмена режимов.
    [bluetooth.ino]
2019-08-25 Синхронизация проекта с актуальной версией проекта от AlexGyver 1.13 - Исправлена Схема5
2019-08-30 исправлена очепятка
2019-08-30 Дополнительные проверки наличия в системе платы MP3 плеера с учетом условной компиляции по #defune USE_MP3
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2019-08-30 Исправлено: рассоединение приложение на смартфоне с матрицей после нескольких выполненных действий в приложении подряд
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2019-09-01 Исправлено: k0cm0 => продолжает работать в режиме AP_STA после получения статического адреса
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2019-09-03 Имя/пароль сети - инициализация дефолтными значениями для того чтобы при первой прошивке подхватывались сразу, а не после перезагрузки
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2019-09-05 Исправлено: После того как тип thisMode сменился с int8_t на byte в одном из предыдущих коммитов - стал неправильно работать переключение режимов назад по списку;
    [custom.ino]
2019-09-05 Исправлены подписи к пинам RX/TX на схеме
2019-09-11 Обновлены библиотеки GyverLibs, исправлена программа для соответствия обновленным библиотекам
    [bluetooth.ino]
2019-09-17 Исправлена функция сохранения строки в EEPROM. Исправлено сохранение режима по времени (выбранный эффект).
    [eeprom.ino]
2019-09-18 Исправлено дрожание текста и артефакты в режимах бегущей строки
    [bluetooth.ino, custom.ino, effects.ino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]
2019-09-18 Исправлено: не сохранялось время бездействия (IDLE)
    [eeprom.ino]
2019-09-22 Исправление длин переменных в буфере.
2019-09-23 Исправлено: при отключенном режиме автоперехода в деморежим не включались из приложения рисование и бегущая строка
    [bluetooth.ino, eeprom.ino]
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2019-09-27 Исправлен размер буфера под имя точки доступа / пароль к точке доступа
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2019-10-31 Исправлено: текущее значение параметра "ориентация часов" не передавалась из матрицы в приложение на смартфоне
    [bluetooth.ino]
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2019-11-03 Исправлено: скорость игр в демо режиме
    [bluetooth.ino, clock.ino, custom.ino]
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2019-11-09 Исправлено: Время звонка будильника считывалось не из той ячейки; При первом запуске имя сети и пароль не инициализировались в EEPROM, что при последующих запусках приводило к попыткам подключения к 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
    [eeprom.ino]
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2019-11-10 Технический. Не рекоммендован к установке. Исправление под версию ядря ESP8266 версиии 2.6 (ранее было 2.5.2) - но сломался звук, не видит звуковую карту Исправлено - расчет будильника, не регулирова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
    [bluetooth.ino, clock.ino, custom.ino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]
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2019-11-15 Исправлено: кнопки "Следующий"/"Предыдущий" не включали игры в демо-режиме
    [bluetooth.ino, clock.ino, custom.ino]
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2019-11-30 Исправление мелких ошибок
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2019-12-17 Исправлено - часть элементов управления не вмещалась на телефоне с малым разрешением экрана
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2020-07-28 Исправлены эффекты Пейнтбол и Водоворот
    [effects.ino]
2020-07-29 Эффекты "Пейнтбол" и "Водоворот" исправлены для работы с неквадратными матрицами (два режима - растягивать / повторять квадратные сегменты)
    [GyverMatrixOS_v1.15.ino, eeprom.ino, effects.ino]
